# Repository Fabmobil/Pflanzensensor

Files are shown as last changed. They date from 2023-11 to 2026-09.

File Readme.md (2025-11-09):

# Fabmobil Logo Pflanzensensor

Dies ist das Repository mit dem Quellcode und allen Informationen zum Fabmobil Pflanzensensor. Weiterführende Erklärungen sind im [Wiki](https://github.com/Fabmobil/Pflanzensensor/wiki) zu finden.

Der Quellcode befindet sich im [Pflanzensensor](https://github.com/Fabmobil/Pflanzensensor/tree/main/Pflanzensensor)-Verzeichnis. Das [Dokumentation](https://github.com/Fabmobil/Pflanzensensor/tree/main/Dokumentation)-Verzeichnis enthält Datenblätter, Schaltpläne und Pinouts der verwendeten Bauteile sowie 3D Modelle für Zubehörteile, die gedruckt werden können. Im [Wiki](https://github.com/Fabmobil/Pflanzensensor/wiki) gibt es weiterführende Informationen und Anleitungen.

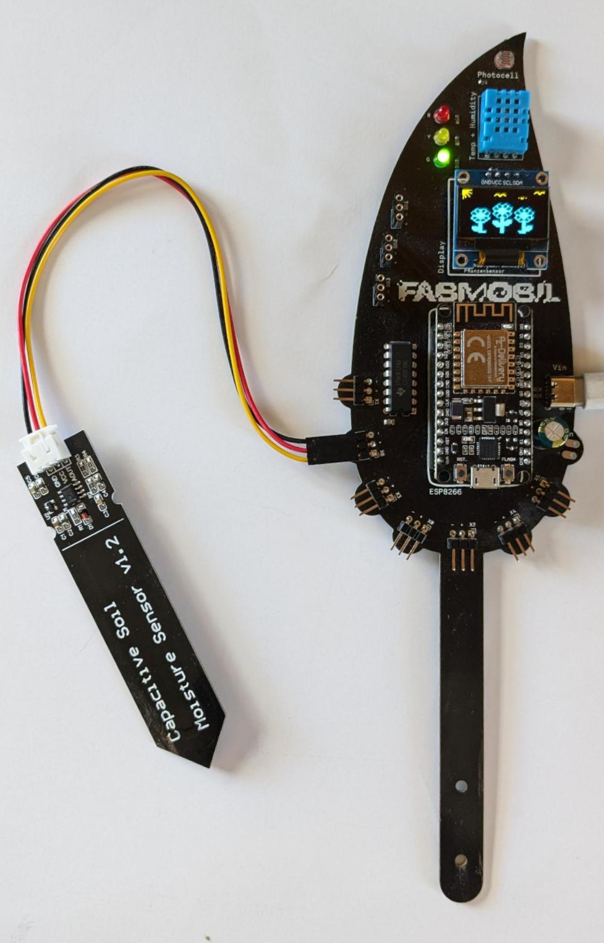
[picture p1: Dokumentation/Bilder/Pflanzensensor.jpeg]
Pflanzensensor

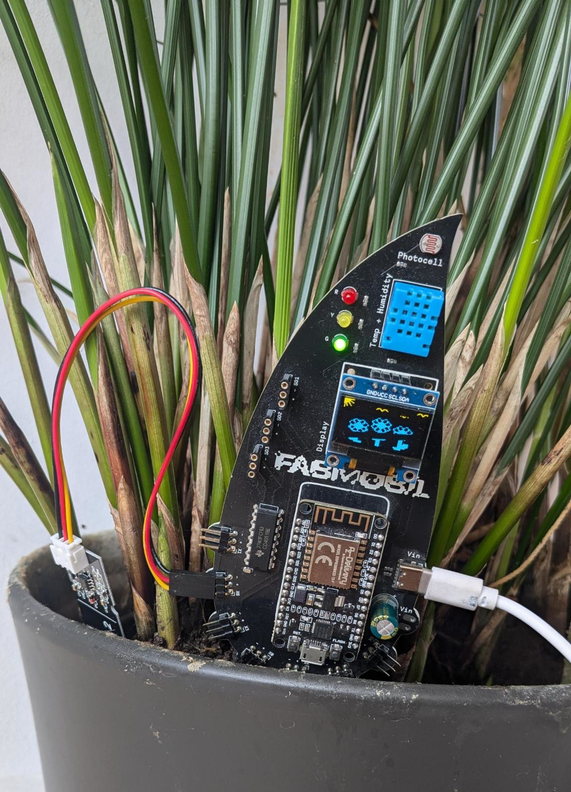
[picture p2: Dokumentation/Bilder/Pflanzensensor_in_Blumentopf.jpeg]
Pflanzensensor in Blumentopf

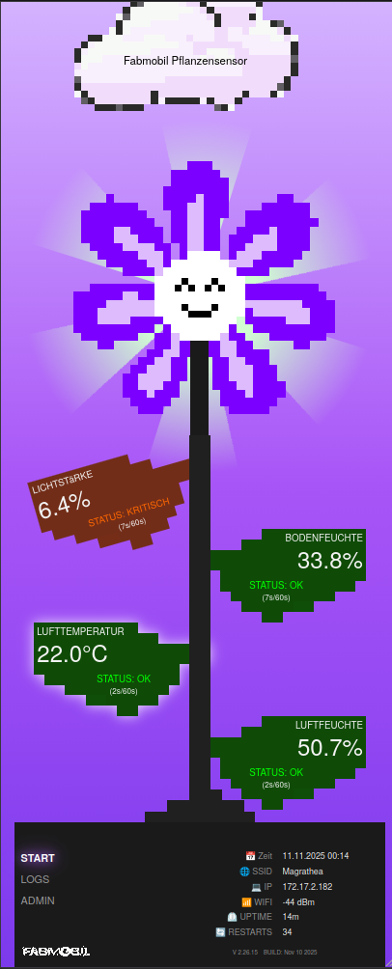
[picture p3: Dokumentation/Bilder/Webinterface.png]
Pflanzensensor Webinterface


[Bosch](https://www.fabmobil.org)

wird gefördert von:

[smk_logo](https://www.smk.sachsen.de/)

und unterstützt von:

[sisax](https://silicon-saxony.de) [Bosch](https://www.bosch.de/) [GlobalFoundries](https://gf.com/) [Bosch](https://www.infineon.com/) [Bosch](https://www.xfab.com/)

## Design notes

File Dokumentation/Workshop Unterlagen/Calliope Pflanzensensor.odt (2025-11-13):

Pflanzensensor Workshop

Willkommen beim Fabmobil Pflanzensensorworkshop! Dieses Dokument fasst die Inhalte und Aufgaben zusammen, die wir in den kommenden 3 Tagen gemeinsam bearbeiten werden und die du benötigst, damit du am Ende einen funktionierenden Pflanzensensor mit nach Hause nehmen kannst.

Achtung: Damit der Pflanzensensor am Ende bei dir zu Hause funktioniert musst du die WLAN Logindaten des WLANs eurer Wohnung eingeben. Du solltest also spätestens an Tag 3 den Namen und das Passwort des WLANs dabei haben, in dem du den Pflanzensensor betreiben willst bzw. vorher sicherstellen, dass du sie aus deinem Smartphone auslesen kannst (Family Link verhindert das z.B. manchmal). Sei achtsam beim Abschreiben: falls nur ein Zeichen falsch ist (Groß- und Kleinschreibung ist relevant!), wird es nicht funktionieren! Der eingesetzte Mikrocontroller kann nur 2,4GHz WLAN. Falls ihr zu Hause also 5 Ghz WLAN und 2,4 GHz WLAN habt benötigst du die Logindaten für letzteres.

# Ablauf

## Tag 1

- Anmeldung, Kennenlernen, Bustour
- Calliope Programmierung

## Tag 2

- Pflanzensensor mit Calliope bauen, kalibrieren, testen
- Arduino IDE kennenlernen

## Tag 3

- Einführung C-Programmierung in Arduino-IDE
- Pflanzensensor zusammenbauen
- Pflanzensensor konfigurieren und flashen
- Sensoren über Webinterface kalibrieren
- Testen
- Abschluss

# Aufgaben

## Kennenlernen

- macht euch ein Namensschild mit Kreppband: wenn ihr nicht fotografiert werden dürft nehmt ihr einen roten Stift, ansonsten nehmt ihr einen schwarzen Stift
- lasst euch den Bus zeigen und erklären
- meldet euch über das Anmeldeformular (https://fabmobil-survey.netlify.app/) an

## Calliope-Programmierung

### Einstieg

Eure WorkshopleiterInnen werden euch eine Einführung ins Thema geben. Wenn ihr die bekommen habt findet euch in Zweiergruppen zusammen. Pro Gruppe benötigt ihr:

- Einen Laptop inkl. Maus und Netzteil
- Einen Calliope inklusive MicroUSB-Kabel
- Ein Calliope Lernkartenbuch

Eure Aufgabe ist es, dass Calliope Lernkartenbuch durchzuarbeiten. Es erklärt euch alles, was ihr über den Calliope, dessen Programmierung und die dazugehörige Entwicklungsumgebung wissen müsst. Am Ende gibt es ein paar kleine Programmierherausforderungen. Wenn ihr die geschafft habt, seid ihr gut vorbereitet für die Programmierung des Pflanzensensors.

#### Bonus

Falls ihr früher als die anderen fertig seid, gibt es folgende Bonusaufgabe:

Sucht euch eine andere Gruppe die auch schon fertig ist. Ihr sollt ihr ein Schnick-Schnack-Schnuck Spiel programmieren, was mit zwei Calliopes gegeneinander gespielt werden kann. Hier ein paar Tipps:

- Zum Senden und Empfangen der Daten zwischen den Calliopes benötigt ihr das Funk-Modul. Ihr findet es hinter dem Button im Online-Editor
- als erstes wählt ihr auf eurem Calliope (z.B.: A = Schere, B = Stein, A + B = Papier) und speichert diese Wahl in einer Variable
- dann schickt diese Wahl an den anderen Calliope
- parallel empfangt ihr die Wahl des anderen Calliope und speichert sie in einer anderen Variable
- diese zwei Variablen müssen dann miteinander verglichen werden: Stein schlägt Schere, Schere schlägt Papier usw.
- danach müsst ihr nur noch das Ergebnis ausgeben: habt ihr gewonnen oder verloren?

### Calliope Pflanzensensor

Meldet euch dann bei euren WorkshopleiterInnen. Die geben euch einen Bodenfeuchtesensor und die notwendigen Kabel, um sie mit dem Calliope zu verbinden. Außerdem wird euch gezeigt, wie ein funktionierendes Pflanzensensorprogramm auf dem Calliope aussehen kann. Ihr sollt jetzt auch ein solches Programm entwerfen. Nutzt dafür das Wissen, was ihr durch die Lernkarten erworben habt. Wenn ihr nicht weiter kommt, fragt die WorkshopleiterInnen um Hilfe. Hier sind auch noch ein paar Tipps und Tricks:

- in der „Beim Start“-Funktion wollt ihr alle eure Variablen und deren Werte definieren. Ihr braucht insgesamt 7: Bodenfeuchte, BodenfeuchteMin, BodenfeuchteMax, TemperaturMin, TemperaturMax, LichtstärkeMin, LichtstärkeMax
- in der „Dauerhaft“-Schleife wollt ihr den Bodenfeuchtesensor an Analogpin P1 auslesen und in einer Variable speichern. Der Sensor arbeitet invertiert: ganz feucht entspricht dem Messwert 1023, ganz trocken dem Messwert 0. Unter den Mathematikblöcken gibt es einen Block der es euch ermöglicht, die Messwerte auf eine 0 – trocken bis 100 – nass Skala umzulegen:

Da diese Funktion eine Kommazahl ausgebt, könnt ihr noch die Runden-Funktion verweden um das Ergebnis auf eine ganze Zahl zu runden:

100

- Beim Drücken der Knöpfe A, B, A+B soll jeweils einer der Messwerte (Temperatur, Lichtstärke, Bodenfeuchte) angezeigt werden und die RGB-LED soll grün oder weiss sein, je nachdem ob der Messwert zwischen Minimum und Maximum liegt oder nicht. Für diesen Vergleich benötigt ihr folgende Blöcke aus dem Logik Bereich:

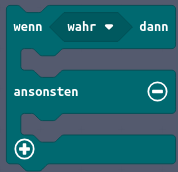
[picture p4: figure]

- Beim Drücken von P0 soll der Sensor alle Messwerte hintereinander anzeigen. Denkt euch jeweils ein schönes Symbol auf der LED-Matrix aus, damit klar ist, welcher Sensor gerade angezeigt wird

Wenn euer Calliope Pflanzensensor funktioniert, könnt ihr ihn mit feuchter und trockener Blumenerde kalibrieren und testen.

## Kennenlernen der Arduino-IDE

Nachdem ihr mit dem Calliope den Einstieg ins Programmieren gefunden habt, geht es mit der Arduino-IDE und der Programmiersprache C++ weiter.

Ihr arbeitet weiterhin in Zweiergruppen und benötigt für diesesen Teil:

- euren Laptop
- einen ESP8266-Microcontroller
- ein MicroUSB-Kabel um den Microcontroller mit eurem PC zu verbinden
- die Software „Arduino IDE“ (sie ist schon auf eurem Laptop installiert)
- den Bodenfeuchtesensor, den ihr schon mit eurem Calliope verwendet habt
- Den Spickzettel zur C-Programmierung (ein PDF im gleichen Verzeichnis wie diese Datei)

Als erstes kopiert ihr euch den Arduino-Ordner aus dem Workshopordner auf dem Netzlaufwerk in den Dokumente Ordner auf eurem Laptop. Dort sollte es schon einen Arduino Ordner geben, löscht ihn vorher damit ihr die aktuellen Versionen des Quellcodes habt:

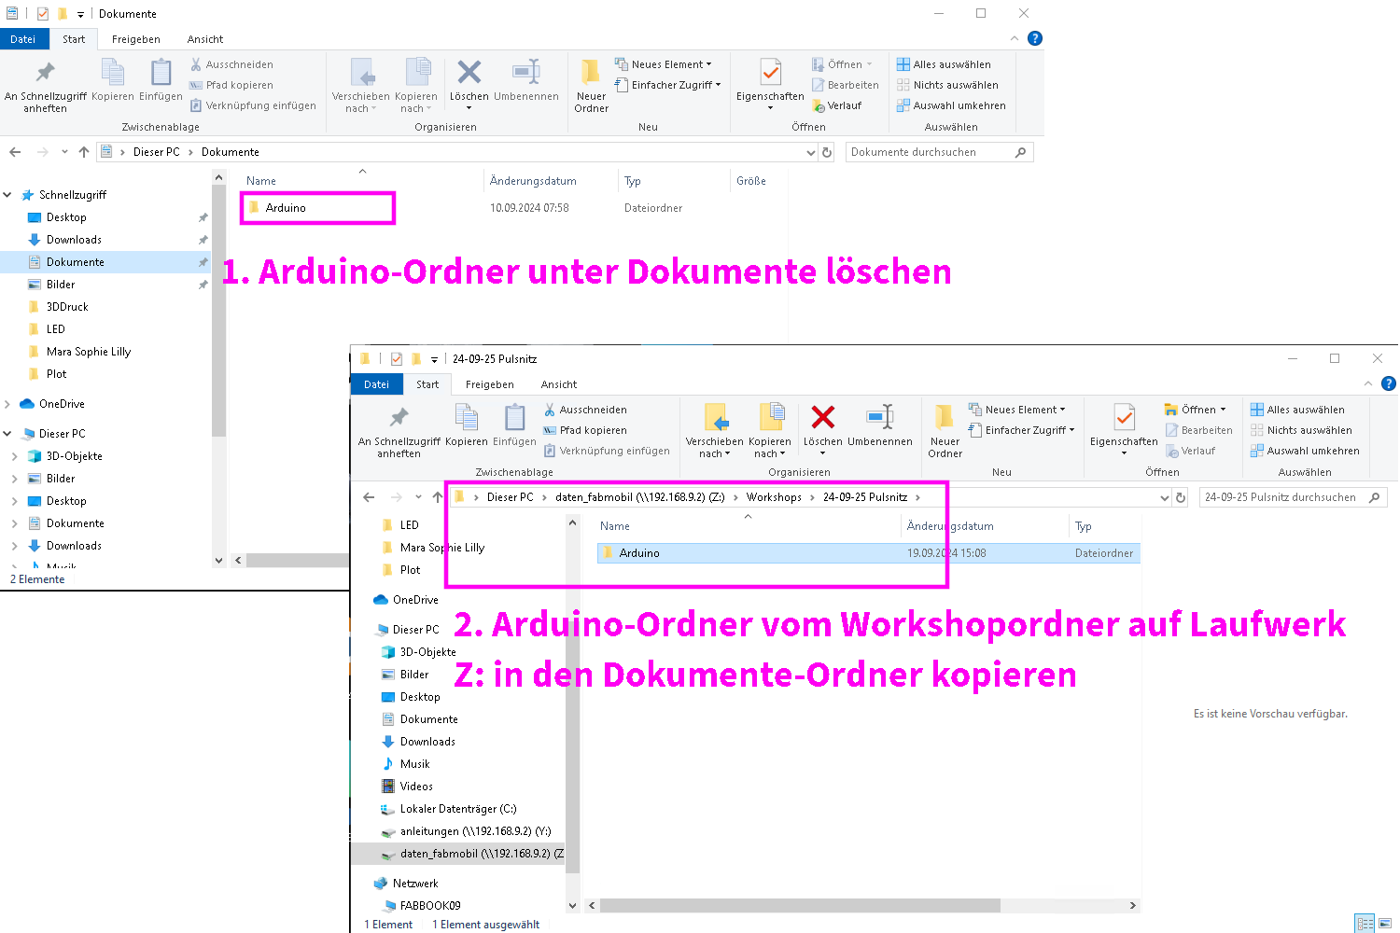
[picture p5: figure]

Dann öffnet ihr die Arduino IDE und schaut euch um. Hier ist ein Bild in dem die wichtigsten Bereiche markiert sind:

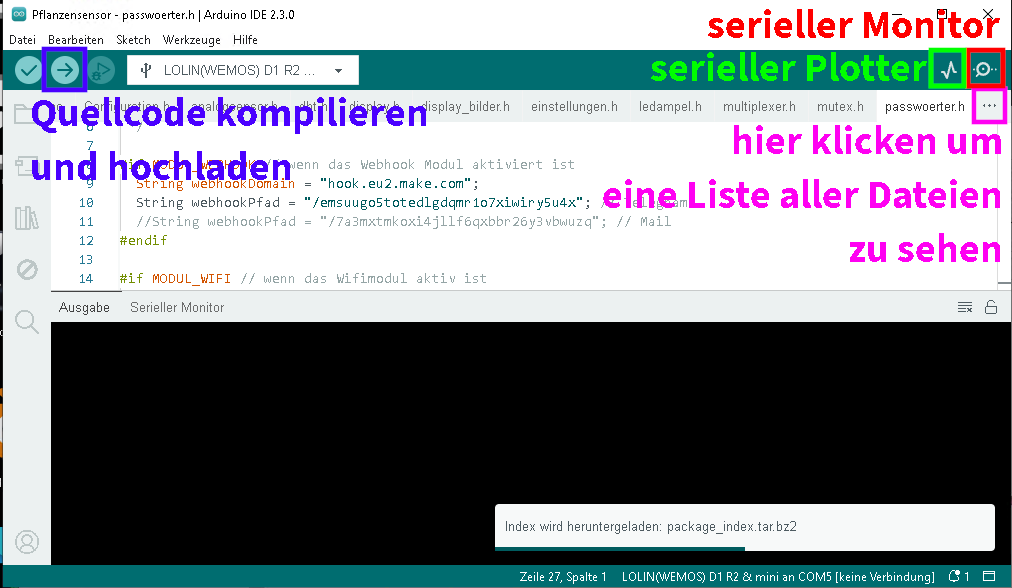
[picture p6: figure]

## Übungen zum Programmieren des ESP8266

Lest euch den Spickzettel durch. Auch wenn die dahinter liegenden Konzepte die Gleichen sind, ist das Programmieren in C ganz anders als die grafische Programmierung des Calliopes. Lasst euch nicht abschrecken: es ist noch kein*e Programmierer*In vom Himmel gefallen. Versucht euch durchzuhangeln und helft euch gegenseitig bzw. fragt die Workshopleiter*Innen wenn ihr nicht weiter kommt!

### Aufgabe 1: LED blinken lassen

- öffne LED.ino im LED Verzeichnis in der Arduino IDE
- verbinde den ESP8266 per USB Kabel mit deinem Laptop
- überspiele das Programm auf deinen ESP8266:
  - klicke unter Werkzeuge auf Board, wähle dann ESP8266 Boards und danach LOLIN(WEMOS) D1 R2 & mini
  - klicke unter Werkzeuge auf Port und wähle den COM-Port mit der höheren Nummer aus. (Falls mit diesem das Überspielen nicht funktioniert, kann es auch sein, dass es der andere Port der Richtige ist)
- überprüfe, ob die interne LED an ist
- erweitere das Programm so, dass die LED immer abwechselnd 1 Sekunde an und 2 Sekunden aus ist. Dazu benötigst du die folgenden zwei zusätzlichen Befehle:
  - digitalWrite(LED, HIGH); schaltet die LED aus
  - delay(3000); pausiert das Programm für 3000ms, also 3 Sekunden

### Aufgabe 2: Feuchtesensor auslesen

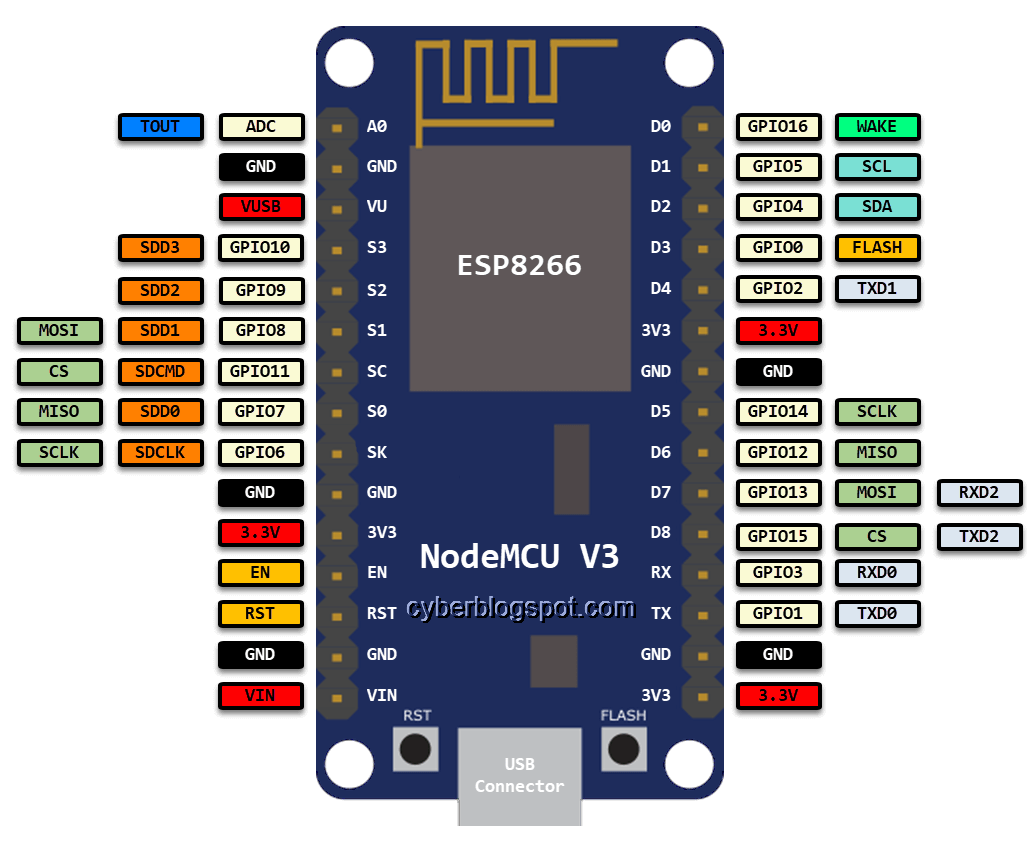
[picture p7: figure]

- Schließe den Bodenfeuchtesensor mit Hilfe von Jumperkabeln an deinen ESP8266 an: rot kommt an 3V3 (Versorgungsspannung), schwarz an GND (Masse) und Gelb an A0 (Sensorwert). Die Pins sind beschriftet bzw. kannst du sie rechts ablesen.
- öffne feuchtesensor.ino in der Arduino IDE
- überspiele das Programm auf deinen ESP8266
- schau dir die Messwerte im seriellen Monitor und im seriellen Plotter an.
- Nimm den Sensor in die Hand und beobachte, wie sich der Wert verändert
- Der Wert liegt immer zwischen 0 und 1024
- deine Aufgabe ist es nun, die interne LED entsprechend dem Wert des Analogsensors blinken zu lassen: bei einem Sensorwert von 100 soll die LED für 100ms an und dann für 100ms aus sein. Bei einem Sensorwert von 1000 soll die LED für 1000ms an und dann für 1000ms aus sein.

### Aufgabe 3: Schwellwertvergleich

- öffne schwellwert.ino in der Arduino IDE
- Vergleiche die Variable schwellwert mit der Variable sensorwert: wenn der sensorwert größer als der schwellwert ist, soll die LED an sein. Wenn der sensorwert kleiner oder gleich dem schwellwert ist, soll die LED aus sein
- wie du einen solchen Vergleich progammierst kannst du hier nachlesen: https://docs.arduino.cc/language-reference/de/struktur/control-structure/else/

### Bonus

Wenn du früher als alle anderen fertig bist, kannst du dir ein Arduinobuch aus der Fabmobil Bibliothek nehmen und dir dort ein kleines Arduino-Programmierprojekt heraussuchen. Sprich mit deinen WorkshopleiterInnen: fast alle der in den Büchern verwendeten Sensoren haben wir auch im Fabmobil und du kannst sie gern ausprobieren.

Die Arduino IDE hat auch viele Beispielprogramme die ausprobiert und verstanden werden wollen. Klick doch mal auf Datei und dann auf Beispiele und schau, was du da so findest!

## Pflanzensensor

Endlich ist es so weit und wir kümmern uns um euren ganz persönlichen Pflanzensensor! Du benötigst:

- einen ESP8266 Mikrocontroller
- einen Bodenfeuchtesensor
- ein Display
- ein Pflanzensensor PCB
- einen Laptop
- ein MicroUSB-Kabel
- Abstandshalter und Schrauben aus Plastik
- 3D-gedruckte Hülle für den Bodenfeuchtsensor

### Zusammenbau

Baue als erstes deinen Pflanzensensor zusammen:

- der ESP8266 kommt in die Fassung auf dem PCB. Achtung: der USB-Port muss nach unten zeigen!
- Das Display kommt in die Fassung über dem ESP8266. Fixiert es mit Plastikabstandshaltern und Schrauben: es gibt entsprechende Löcher auf dem PCB und im Display
- steckt den Bodenfeuchtesensor an: er kommt an den Port der mit X6 gelabelt ist. Passt auf die Orientierung des Kabels auf: - am PCB muss an GND am Sensor
- Setzt das Gehäuse um den oberen Teil des Bodenfeuchtesensors. Es schützt die elektronischen Bauteile davor, dass sie beim Blumengießen Spritzwasser abbekommen und dadurch eventuell kaputt gehen.
  - Falls das Gehäuse nicht hält könnt ihr es mit Klebeband oder Sekundenkleber zusammenkleben.

### Bespielen des ESP8266 mit dem Pflanzensensorprogramm

Folgende Schritte sind zu tun:

- öffnet die Pflanzensensor.ino – Datei in eurer Arduino IDE. Sie liegt im Dokumente/Arduino/Pflanzensensor-Ordner
- der Quellcode des Pflanzensensorprogramms besteht aus vielen Dateien. Sie werden alle automatisch geöffnet und ihr seht sie in der Leiste über dem Editor in der Arduino IDE. Schaut euch ruhig um und in die Dateien rein, falls es euch interessiert. Es ist allerdings wichtig, dass ihr nichts verändert, denn dann ist die Chance groß, dass ihr Fehler einbaut und das Programm sich später nicht mehr überspielen lässt
- Verändern müsst ihr nur die passwoerter.h- Datei. Falls ihr diese in der Leiste mit den Dateinamen nicht findet könnt ihr rechts auf die drei … klicken, dann bekommt ihr eine Liste mit allen geöffneten Dateien angezeigt und könnt sie dort auswählen
- Öffnet die passwoerter.h-Datei und tragt dort die Daten des WLANs ein, in dem ihr den Pflanzensensor betreiben wollt:
  - Ihr könnt bis zu drei verschiedene WLANs konfigurieren. Die Variablen wifiSsid1, wifiSsid2 und wifiSsid3 speichern den Namen des WLANs und die Variablen wifiPassword1, wifiPassword2 und wifiPassword3 speichern das Passwort der WLANs. Der eigentliche Name des WLANs bzw. das Passwort kommt zwischen die Anführungszeichen.
  - Passt auf, dass ihr die schon ausgefüllten Fabmobil WLAN Daten nicht löscht oder verändert, sonst kann sich euer Sensor nicht mit dem WLAN im Fabmobil verbinden und ihr könnt euch nicht mit eurem Laptop zum Webinterface verbinden
  - Falls ihr plant, den Sensor mobil zu benutzen, ist es eventuell sinnvoll, auch die Daten eures Handy WLAN Hotspots einzutragen
- Danach könnt ihr den Quellcode kompilieren und überspielen so wie ihr das bei den Programmierübungen auch schon gemacht habt.
- Abschließend müsst ihr noch ein paar Extradateien überspielen. Das funktioniert, in dem ihr [Strg] + [Shift] + [P] gleichzeitig drückt, upload eingebt und Upload LittleFS to Pico/ESP8266/ESP32 auswählt.
- Öffnet jetzt den seriellen Monitor und startet den ESP neu. Achtet auf die Zeile Start von Wifi-Modul…: jetzt versucht sich euer Pflanzensensor mit dem WLAN zu verbinden. Wenn das geklappt hat wird euch auf dem Display und auch im seriellen Monitor die IP Adresse angezeigt, die der Pflanzensensor bekommen hat. IP Adressen bestehen aus vier Zahlen getrennt durch einen Punkt und sehen z.B. so aus: 192.168.9.199. Merkt oder kopiert sie euch.

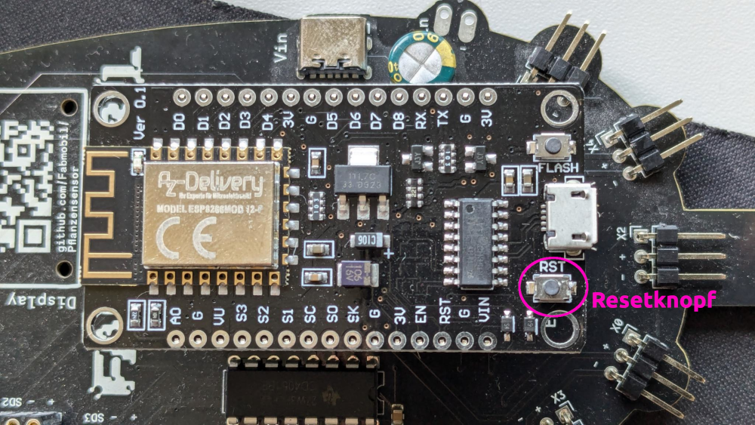
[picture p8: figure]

- Gebt diese IP-Adresse jetzt im Browser eures Laptops als Adresse ein. Ihr solltet jetzt auf dem Webinterface eures Pflanzensensors landen.

### Kennenlernen des Webinterfaces

- Schaut euch das Webinterface eures Pflanzensensors im Browser an, versteht was es darstellt, findet die Adminseite und lest hier (https://github.com/Fabmobil/Pflanzensensor/wiki/Webinterface) nach, was da alles eingestellt werden kann.

### Kalibrieren der Sensoren

Damit euer Bodenfeuchtesensor richtig funktioniert, müsst ihr ihn jetzt kalibrieren:

- Stecke den Bodenfeuchtesensor in sehr feuchte Erde. Achtung: Du solltest den Sensor immer gleich tief in die Erde stecken damit die Messung einigermaßen genau ist. Ein Sensor, der nur halb in der Erde steckt, wird dir andere Messwerte anzeigen als einer, der ganz in der Erde steckt. Ein weißer Strich auf dem Sensor kurz unterhalb des Gehäuses markiert die Stelle, bis zu der ihr den Sensor in die Erde stecken solltet.
- Geh auf die Adminseite deines Pflanzensensors, finde dort den Bodenfeuchte-Bereich und lese den aktueller absoluter Messwert ab. Dieser muss nun darunter bei Maximalwert eingetragen werden.
- Stecke den Bodenfeuchtesensor in sehr trockene Erde.
- Lies wieder den aktuellen absoluten Messwert ab und trage ihn diesmal bei Minimalwert ein.
- Speichere deine Änderungen.
- Jetzt ist dein Bodenfeuchtesensor kalibriert. Falls du allerdings später zu Hause andere Erde hast kann es sein, dass du die Kalibrierung dort noch einmal wiederholen musst.
- Wenn du willst, kannst du auch deinen Helligkeitssensor kalibrieren: bedecke ihn damit es ganz dunkel ist und halte ihn in die Mittagssonne. Die voreingestellten Werte passen aber ganz gut, so dass du das nicht zwingend machen musst.

### Einstellen der Grenzen für die LED Ampel

Die Grenzwerte der LED Ampel für die unterschiedlichen Sensoren können auf der Adminseite deines Pflanzensensors eingestellt werden:

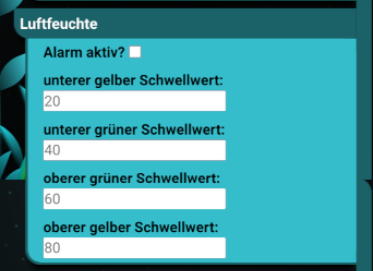
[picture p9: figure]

Diese Schwellwerte sind folgendermaßen definiert:

Abhängig davon, was die Pflanze die du mit dem Sensor überwachen willst für Bedürftnisse hat, stellst du jetzt die Skale für die unterschiedlichen Sensoren ein.

### Bonus

Wenn ihr noch genügend Zeit und Motivation habt könnt ihr eurem Pflanzensensor noch beibringen, euch per Telegram oder Email zu benachrichtigen, falls eure Pflanze eure Aufmerksamkeit benötigt. Dazu müsst ihr:

- in der Arduino IDE die Datei einstellungen.h öffnen und in der Zeile #define MODUL_WEBHOOK false das false zu einem true ändern. Das aktiviert das Webhook-Modul, welches für die Benachrichtigung notwendig ist.
- Öffnet dann diese Anleitungsseite (https://github.com/Fabmobil/Pflanzensensor/wiki/Webhook) in eurem Browser und arbeitet sie durch.

## Wie weiter?

Ihr bekommt ja jede*r einen Pflanzensensor mit nach Hause. Im besten Fall wisst ihr nun, wie ihr ihn konfigurieren und einsetzen könnt.
Unter https://www.github.com/fabmobil/pflanzensensor findet ihr die Dokumentation und den Quellcode zu eurem Sensor. Dort werden auch Aktualisierungen des Pflanzensensor-Programms veröffentlicht. Falls ihr in ein paar Wochen vergessen habt, wir ihr das Pflanzensensor Programm flashen könnt, steht das dort auch geschrieben. Wusstet ihr, dass ihr noch mehr Bodenfeuchtesensoren anschließen könnt um mehrere Pflanzen gleichzeitig zu überwachen? Oder das euer Pflanzensensor euch per Mail oder Telegram Bescheid sagen kann, wenn eure Pflanze euch braucht (https://github.com/Fabmobil/Pflanzensensor/wiki/Webhook)?
Falls ihr Fragen oder Anregungen habt könnt ihr uns auch gern per Email kontaktieren: pflanzensensor@fabmobil.org

Vielleicht findet ihr den Pflanzensensor ja aber auch doof und wollt lieber ganz andere Sachen mit eurem WLAN-fähigen Mikroprozessor machen? Kein Problem: zieht ihn einfach aus dem PCB raus und widmet ihn um. Das Internet ist voll mit Tutorials und Anleitungen, wenn ihr Inspiration braucht könnt ihr zum Beispiel hier mal schmökern: https://polluxlabs.net/esp8266-projekte/

Viel Spaß❣️

# Verwendete Programme und Links

## Calliope

- Calliope Lernkarten aus dem Fabmobil
- Calliope Online Editor (https://makecode.calliope.cc/)
- Einfühungs Tutorial auf Youtube (https://www.youtube.com/watch?v=76ryLoWfYhs)

## Pflanzensensor

- Arduino IDE (https://www.arduino.cc/en/software)
- Pflanzensensor Quellcode und Erklärungen (https://github.com/Fabmobil/Pflanzensensor)
- Anleitungen im Pflanzensensor Wiki:
  - Pflanzensensor konfigurieren und bespielen (https://github.com/Fabmobil/Pflanzensensor/wiki/Update)
  - Erklärungen zum Webinterface (https://github.com/Fabmobil/Pflanzensensor/wiki/Webinterface)
  - Webhook für Telegram- oder Mailbenachrichtigungen einrichten (https://github.com/Fabmobil/Pflanzensensor/wiki/Webhook)
  - make.com Website für Mail- oder Telegrambenachrichtgungen (https://www.make.com/en)

## Fabmobil und Silicon Saxony

- 💜 Fabmobil Homepage (https://fabmobil.org/) 💜
- 🩵 Silicon Saxony (https://silicon-saxony.de/) 🩵
- 🧡 Bosch (https://www.bosch.de/) 🧡
- 💚 Global Foundries (https://gf.com/) 💚
- 🩷 Infineon (https://www.infineon.com/) 🩷
- 🩶 Xfab (https://www.xfab.com/) 🩶

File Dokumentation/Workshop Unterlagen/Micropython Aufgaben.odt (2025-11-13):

# Aufgaben

## Den ESP8266 einrichten

Öffne das Programm, schließe deinen ESP8266 über USB an und gehe direkt auf den Punkt Werkzeuge → Optionen:

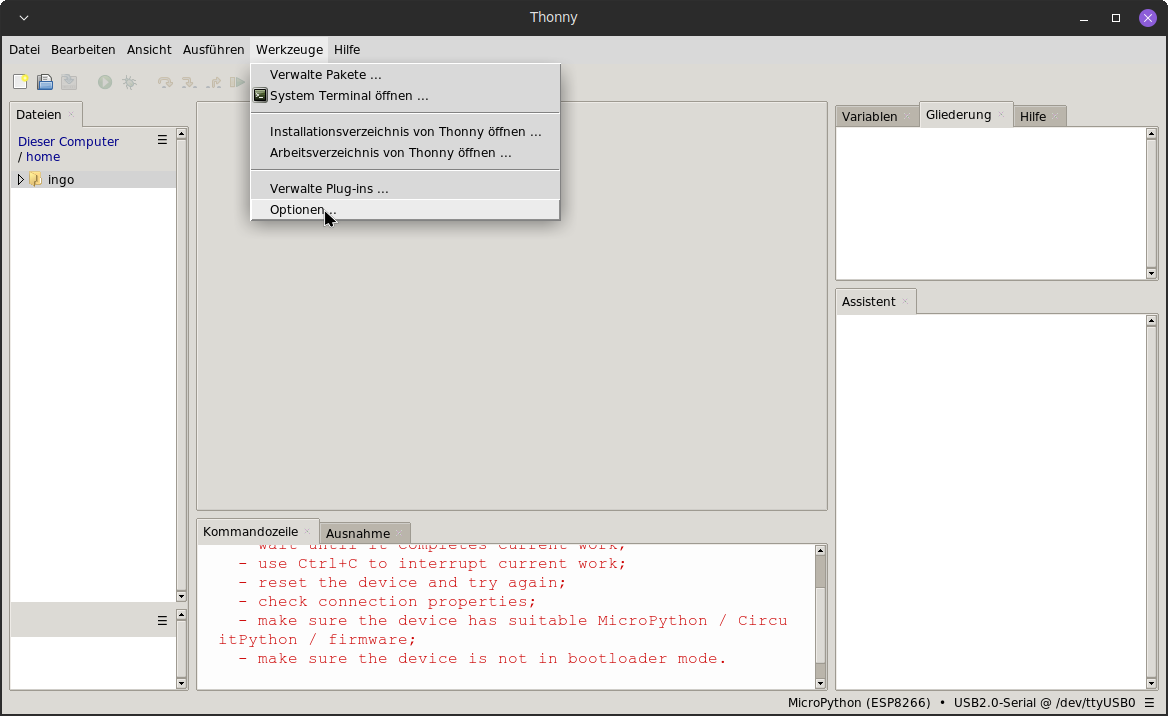
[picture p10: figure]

Dort sollte unter dem Reiter „Interpreter“ euer ESP8266 automatisch erkannt werden. Falls ihr ihn nicht finden könnt, meldet ihr euch bei uns.

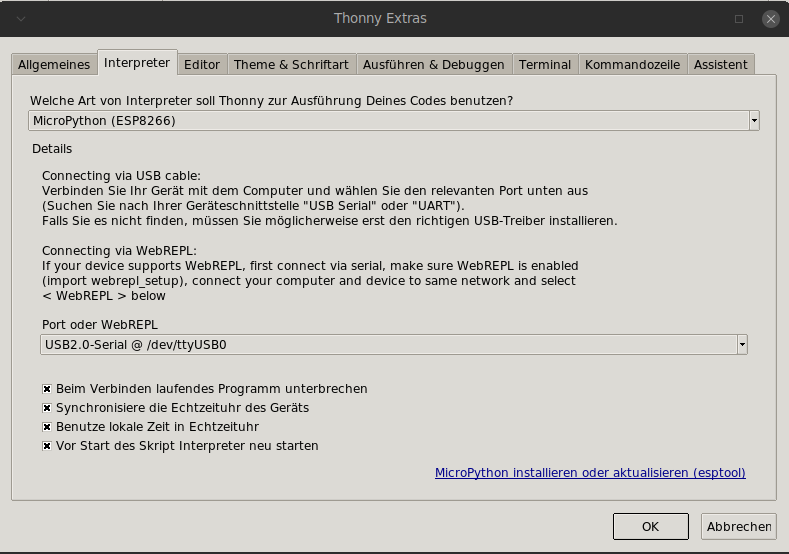
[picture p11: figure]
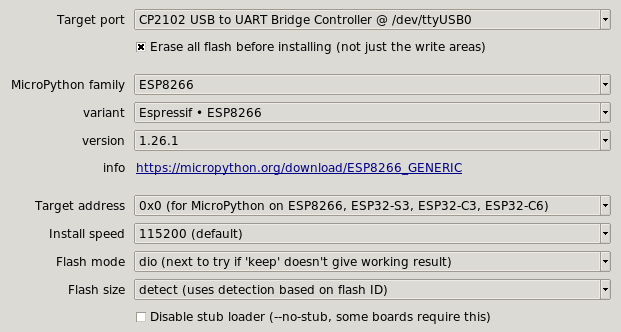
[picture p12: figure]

## Hello World

Schreibe den Befehl

print(„Hallöchen“)

in die Kommandozeile unten in Thonny hinein und drücke Enter. Erscheint dein Text in der nächsten Zeile?

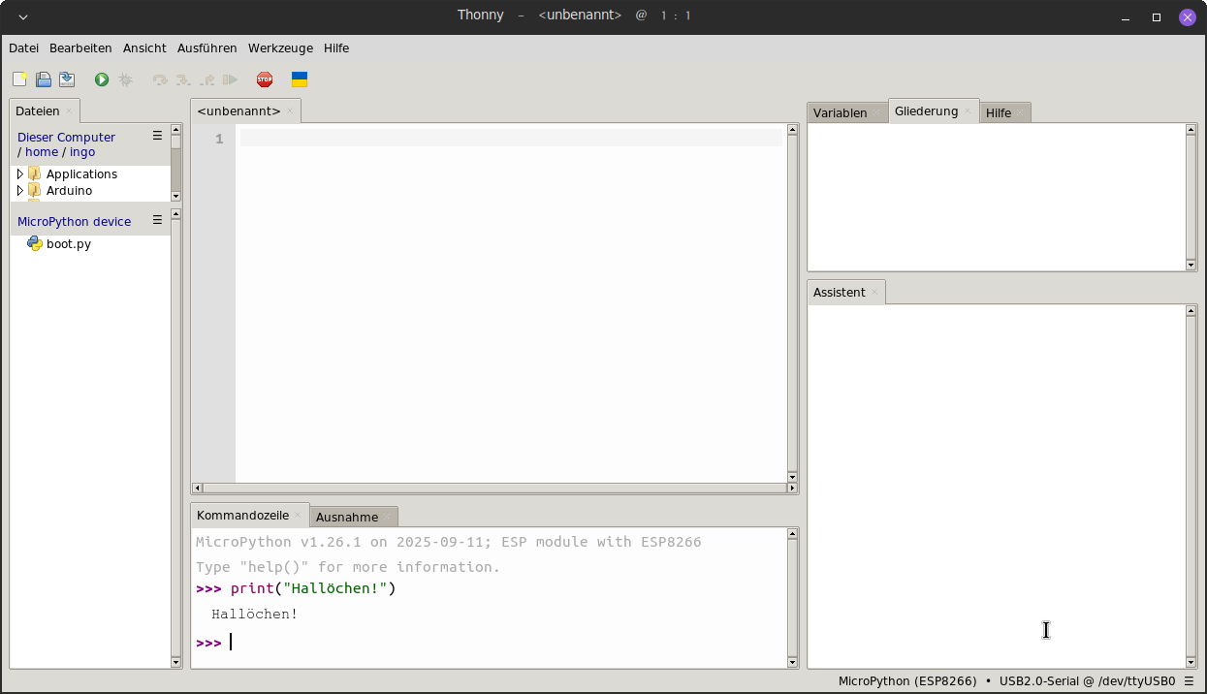
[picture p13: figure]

Der Befehl print() ist mit dem „Zeige Text“-Block von Makecode vergleichbar, den wir vorher auch schon genutzt haben, um uns die Sensorwerte anzeigen zu lassen.

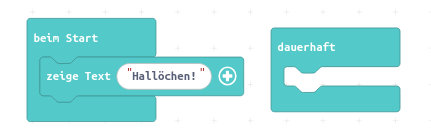
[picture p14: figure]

Aufgabe: Lege eine Variable text mit dem Inhalt „Hallöchen“ an:

text = „Hallöchen“

Gebe mit print() die Variable ausgeben und überprüfe den Inhalt.

Aufgabe: Lege die Variable zahl mit dem Inhalt 3 an:

zahl = 3

Erhöhe die Variable um 4 und gebe den neuen Wert mit print() aus.

## Blinky LED

Füge die externe Bibliothek Pin mit der folgenden Zeile hinzu:

from machine import Pin

Bibliotheken sind so etwas wie Plugins. Ab jetzt kannst du den Befehl Pin() verwenden.

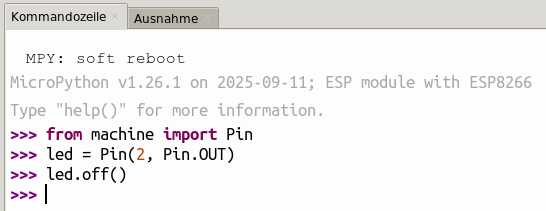
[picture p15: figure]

Achtung! Die LED auf dem ESP geht mit led.off() an und mit led.on() wieder aus – es ist genau umgedreht.

Aufgabe: Probiere die anderen LEDs auf dem Pflanzensensor aus. Sie sind an die folgenden Pins angeschlossen:
grün – Pin 14
gelb – Pin 12
rot – Pin 13

Aufgabe: Was ist led genau? Tipp: Die Struktur mit dem = Zeichen haben wir in der letzten Aufgabe schon benutzt.

## Poesie

In dem Programmtext-Fenster kannst du mehrere Befehle jeweils in eine Zeile untereinander schreiben. Diese werden der Reihe nach ausgeführt, wenn du auf den grünen Pfeil klickst.

Programmtext-Fenster

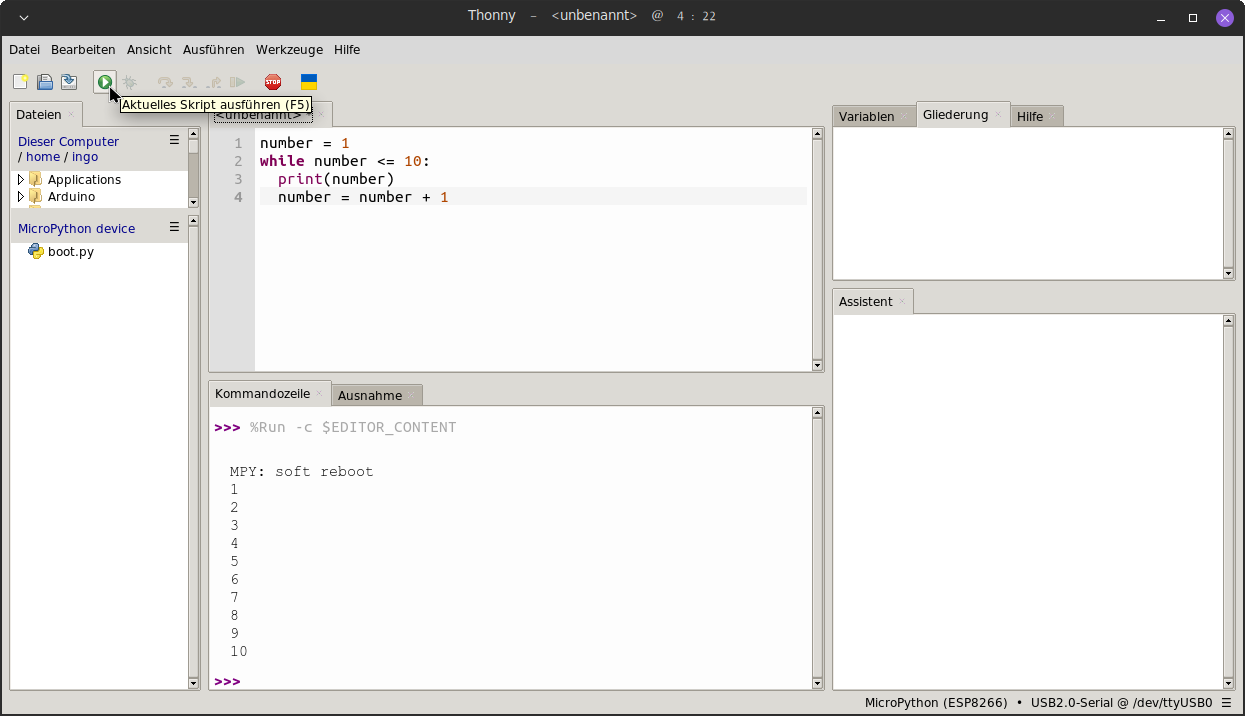
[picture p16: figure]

Aufgabe: Lasse dir ein selber ausgedachtes Gedicht mit 4-5 Zeilen untereinander ausgeben.

Aufgabe: Lasse nach jeder Zeile des Gedichts eine beliebige LED für jeweils eine Sekunde aufleuchten und anschließend wieder ausgehen. Dafür benötigst du den Befehl sleep(sekunden) , damit wartet dein ESP einfach für die in sekunden eingetragene Zeit, z.B. sleep(3) für 3s. Den Befehl sleep() kannst du erst benutzen, nachdem du ihn mit from time import sleep eingebunden hast.

### Schleifen

Eine Schleife wiederholt einen Block des Quellcodes. In Makecode habt ihr das z.B. für die Lärmampel benutzt:

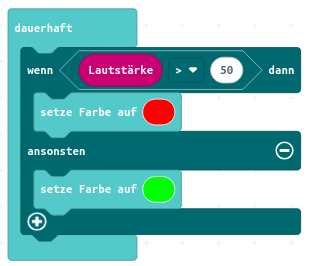
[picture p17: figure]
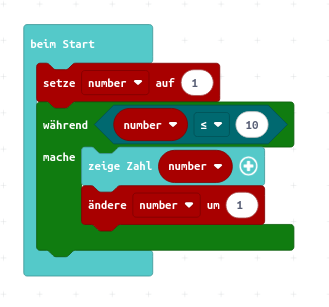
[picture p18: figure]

In Python gibt es stattdessen die while-Schleife (englisch für „während“):

Aufgabe: Schreibe ein Programm, das Zahlen von 1 bis 10 ausgibt (so wie rechts). Achte in Python auf die gleichen Einrückungen für den Block!

Aufgabe: Wenn dir jetzt noch nicht klar ist, wie while funktioniert, Google nach weiteren Informationen oder lasse es dir von einem Chatbot erklären.

Aufgabe: Lasse jetzt die Zahlen endlos nach oben zählen, solange der ESP Strom hat (vergleichbar mit der Dauerhaft-Schleife von Makecode).

Bonus: Lasse jetzt noch bei jeder Zahl eine LED kurz aufblinken.

## Den Sensor auslesen

Um den Sensor auszulesen benötigen wir die Bibliothek

from machine import ADC

Lege eine Variable bodenfeuchte_sensor mit dem Inhalt ADC(0) an.

Lese den aktuellen Messwert ein mit: bodenfeuchte_sensor.read()

Aufgabe: Gebe den aktuellen Messwert dauerhaft aus, solange der ESP Strom hat. Füge zwischen zwei Messungen eine kleine Pause ein, damit die Zahlen nicht zu schnell kommen.

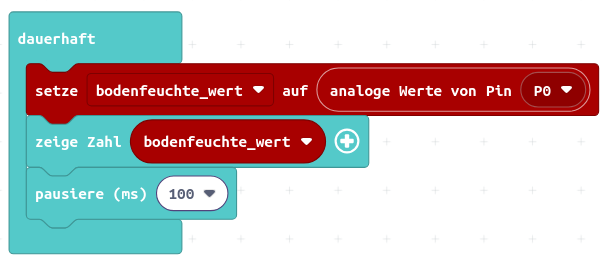
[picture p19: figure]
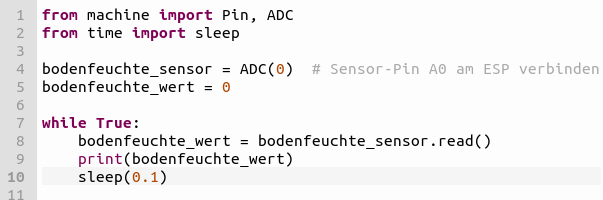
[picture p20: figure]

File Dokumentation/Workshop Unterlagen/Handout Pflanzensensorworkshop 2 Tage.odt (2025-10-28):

Pflanzensensor Workshop

Willkommen beim Fabmobil Pflanzensensorworkshop! Dieses Dokument fasst die Inhalte und Aufgaben zusammen, die wir in den kommenden 2 Tagen gemeinsam bearbeiten werden und die du benötigst, damit du am Ende einen funktionierenden Pflanzensensor mit nach Hause nehmen kannst.

# Ablauf

## Tag 1

- Anmeldung, Kennenlernen, Bustour
- Calliope Programmierung:
  - Kennenlernen und Programmierchallenges
  - Pflanzensensor bauen, programmieren, kalibrieren, testen

## Tag 2

- Fertigstellen Calliope Pflanzensensor
- Programmierübungen mit Micropython auf dem ESP8266
- Pflanzensensor zusammenbauen
- Pflanzensensor flashen
- Pflanzensensor kennenlernen und über Webinterface einstellen
- Testen
- Abschluss

# Aufgaben

## Kennenlernen

- macht euch ein Namensschild mit Kreppband: wenn ihr nicht fotografiert werden dürft nehmt ihr einen roten Stift, ansonsten nehmt ihr einen schwarzen Stift
- lasst euch den Bus zeigen und erklären
- meldet euch über das Anmeldeformular (https://fabmobil-survey.netlify.app/) an

## Calliope-Programmierung

### Einstieg

Eure WorkshopleiterInnen werden euch eine Einführung ins Thema geben. Wenn ihr die bekommen habt findet euch in Zweiergruppen zusammen. Pro Gruppe benötigt ihr:

- Einen Laptop inkl. Maus und Netzteil
- Einen Calliope inklusive MicroUSB-Kabel
- Ein Calliope Lernkartenbuch

Eure Aufgabe ist es, dass Calliope Lernkartenbuch durchzuarbeiten. Es erklärt euch alles, was ihr über den Calliope, dessen Programmierung und die dazugehörige Entwicklungsumgebung wissen müsst. Am Ende gibt es ein paar kleine Programmierherausforderungen. Wenn ihr die geschafft habt, seid ihr gut vorbereitet für die Programmierung des Pflanzensensors.

#### Bonus 1

Versucht auch mal in makecode.calliope.cc von der „Blöcke“-Ansicht auf die „Python“-Ansicht umzuschalten. Python ist eine sehr anfängerfreundliche Programmiersprache und alles, was ihr bisher in Blöcken programmiert habt, kann auch in Python programmiert werden. Schaut euch eine der Programmierchallenges als Pythoncode an. Versteht ihr, was ihr seht? Gelingt es euch, eine andere Programmierchallenge in Python zu schreiben anstatt sie mit Blöcken zu programmieren?

#### Bonus 2

Sucht euch eine andere Gruppe die auch schon fertig ist. Ihr sollt ihr ein Schnick-Schnack-Schnuck Spiel programmieren, was mit zwei Calliopes gegeneinander gespielt werden kann. Hier ein paar Tipps:

- Zum Senden und Empfangen der Daten zwischen den Calliopes benötigt ihr das Funk-Modul. Ihr findet es hinter dem Button im Online-Editor
- als erstes wählt ihr auf eurem Calliope (z.B.: A = Schere, B = Stein, A + B = Papier) und speichert diese Wahl in einer Variable
- dann schickt diese Wahl an den anderen Calliope
- parallel empfangt ihr die Wahl des anderen Calliope und speichert sie in einer anderen Variable
- diese zwei Variablen müssen dann miteinander verglichen werden: Stein schlägt Schere, Schere schlägt Papier usw.
- danach müsst ihr nur noch das Ergebnis ausgeben: habt ihr gewonnen oder verloren?

### Calliope Pflanzensensor

Meldet euch dann bei euren WorkshopleiterInnen. Die geben euch einen Bodenfeuchtesensor und die notwendigen Kabel, um sie mit dem Calliope zu verbinden. Außerdem wird euch gezeigt, wie ein funktionierendes Pflanzensensorprogramm auf dem Calliope aussehen kann. Ihr sollt jetzt auch ein solches Programm entwerfen. Nutzt dafür das Wissen, was ihr durch die Lernkarten erworben habt. Wenn ihr nicht weiter kommt, fragt die WorkshopleiterInnen um Hilfe. Hier sind auch noch ein paar Tipps und Tricks:

- in der „Beim Start“-Funktion wollt ihr alle eure Variablen und deren Werte definieren. Ihr braucht insgesamt 7: Bodenfeuchte, BodenfeuchteMin, BodenfeuchteMax, TemperaturMin, TemperaturMax, LichtstärkeMin, LichtstärkeMax
- in der „Dauerhaft“-Schleife wollt ihr den Bodenfeuchtesensor an Analogpin P1 auslesen und in einer Variable speichern. Der Sensor arbeitet invertiert: ganz feucht entspricht dem Messwert 1023, ganz trocken dem Messwert 0. Unter den Mathematikblöcken gibt es einen Block der es euch ermöglicht, die Messwerte auf eine 0 – trocken bis 100 – nass Skala umzulegen:

Da diese Funktion eine Kommazahl ausgebt, könnt ihr noch die Runden-Funktion verweden um das Ergebnis auf eine ganze Zahl zu runden:

100

- Beim Drücken der Knöpfe A, B, A+B soll jeweils einer der Messwerte (Temperatur, Lichtstärke, Bodenfeuchte) angezeigt werden und die RGB-LED soll grün oder weiss sein, je nachdem ob der Messwert zwischen Minimum und Maximum liegt oder nicht. Für diesen Vergleich benötigt ihr folgende Blöcke aus dem Logik Bereich:


- Beim Drücken von P0 soll der Sensor alle Messwerte hintereinander anzeigen. Denkt euch jeweils ein schönes Symbol auf der LED-Matrix aus, damit klar ist, welcher Sensor gerade angezeigt wird

Wenn euer Calliope Pflanzensensor funktioniert, könnt ihr ihn mit feuchter und trockener Blumenerde kalibrieren und testen.

## Programmierübungen mit Micropython auf dem ESP8266

Nachdem ihr mit dem Calliope den Einstieg ins Programmieren gefunden habt, geht es mit der Entwicklungsumgebung Thonny und der Programmiersprache Python weiter.

Ihr arbeitet weiterhin in Zweiergruppen und benötigt für diesesen Teil:

- euren Laptop
- einen ESP8266-Microcontroller
- ein MicroUSB-Kabel um den Microcontroller mit eurem PC zu verbinden
- die Software „Thonny“ (sie ist schon auf eurem Laptop installiert)
- den Bodenfeuchtesensor, den ihr schon mit eurem Calliope verwendet habt

TBC

## Pflanzensensor

Endlich ist es so weit und wir kümmern uns um euren ganz persönlichen Pflanzensensor! Du benötigst:

- einen ESP8266 Mikrocontroller
- einen Bodenfeuchtesensor
- ein Display
- ein Pflanzensensor PCB
- einen Laptop
- ein MicroUSB-Kabel
- Abstandshalter und Schrauben aus Plastik
- 3D-gedruckte Hülle für den Bodenfeuchtsensor

### Zusammenbau

Baue als erstes deinen Pflanzensensor zusammen:

- der ESP8266 kommt in die Fassung auf dem PCB. Achtung: der USB-Port muss nach unten zeigen!
- Das Display kommt in die Fassung über dem ESP8266. Fixiert es mit Plastikabstandshaltern und Schrauben: es gibt entsprechende Löcher auf dem PCB und im Display
- steckt den Bodenfeuchtesensor an: er kommt an den Port der mit X6 gelabelt ist. Passt auf die Orientierung des Kabels auf: - am PCB muss an GND am Sensor
- Setzt das Gehäuse um den oberen Teil des Bodenfeuchtesensors. Es schützt die elektronischen Bauteile davor, dass sie beim Blumengießen Spritzwasser abbekommen und dadurch eventuell kaputt gehen.
  - Falls das Gehäuse nicht hält könnt ihr es mit Klebeband oder Sekundenkleber zusammenkleben.

### Bespielen des ESP8266 mit dem Pflanzensensorprogramm

Es wird einen oder zwei Arbeitsplätze geben, an denen euer ESP8266 mit dem Fabmobil Pflanzensensor Programm bespielt wird. Geht dort hin und lasst euren Pflanzensensor aufspielen.

### Logdateien mitlesen

Du kannst die Logdateien deines Pflanzensensors mit deinem Laptop mitlesen. Dazu schließt du ihn per USB an deinen Laptop an, öffnest das Programm „Arduino IDE“ und dort unter „Werkzeuge“ den „serieller Monitor“. Du solltest dann das Log des Pflanzensensors sehen:

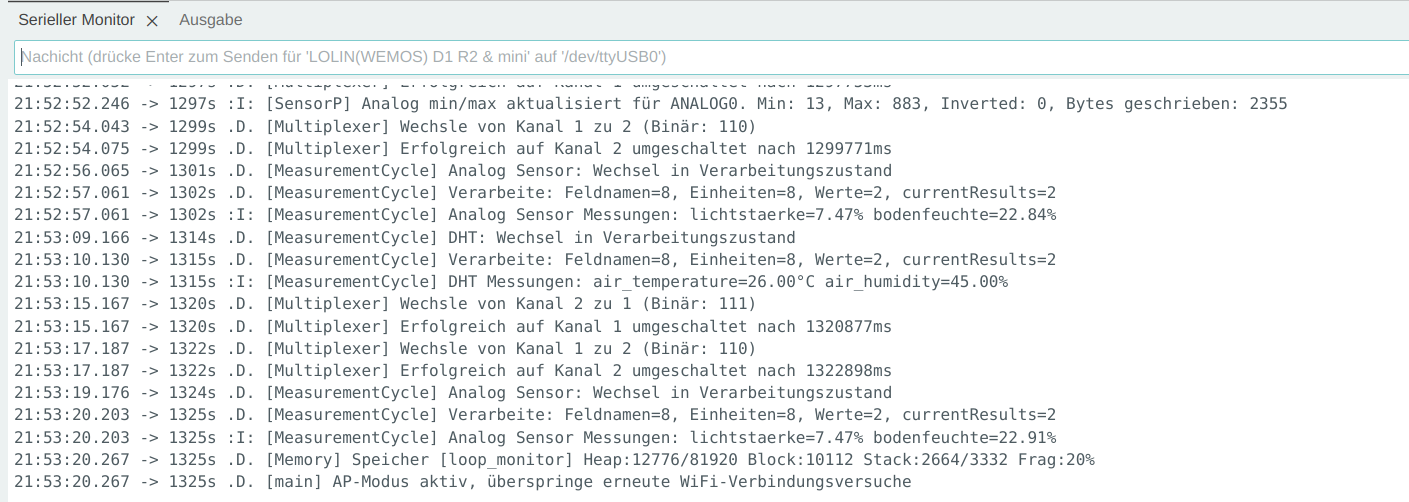
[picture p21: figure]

- Falls du nur unleserliche Zeichen erkennen kannst stimmt die Baudrate (Übertragungsgeschwindigkeit der Daten) nicht. Sie muss 115200 sein.
- Falls du gar keine Verbindung mit dem Pflanzensensor bekommst kann es sein, dass du den Port noch manuell festlegen musst: wähle „Werkzeuge“ in der Menüleiste und finde „Port“. Dort nimmst du den COM-Port mit der höheren Nummer. Falls das nicht funktioniert, versuche die anderen angebotenen COM-Ports durch

### Webinterface aufrufen

Finde die IP Adresse deines Pflanzensensors heraus. Er sollte mit dem Fabmobil WLAN verbunden sein und auf seinem Display seine IP Adresse anzeigen. Auch im Log wird sie regelmäßig angezeigt. Du musst sie in die Adressleiste deines Browsers einfügen:

Dann sollte sich die Pflanzensensorseite öffnen, sie sieht in etwa so aus:

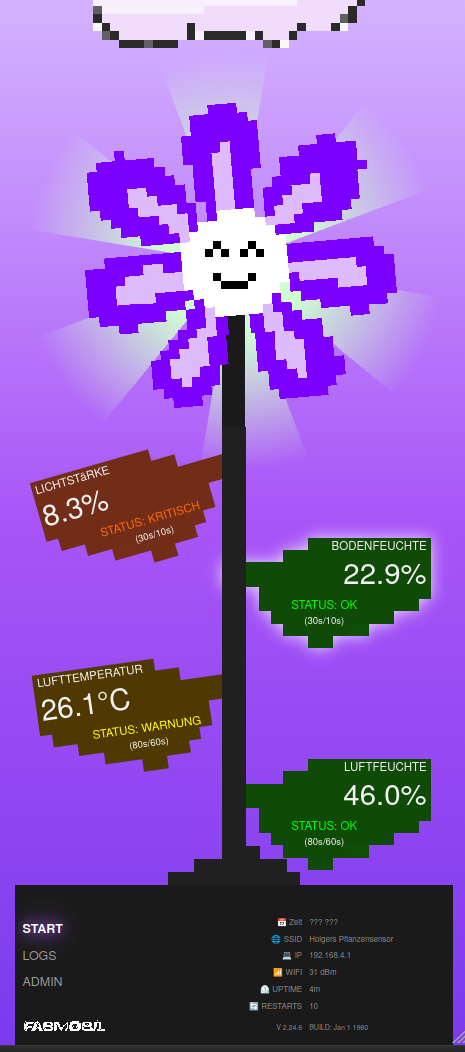
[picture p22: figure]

Schau dich um. Deine Pflanze zeigt die Werte der Sensoren an. Da diese noch nicht kalibriert sind, kann es sein das deine Pflanze traurig ist. Keine Sorge, wir ändern das gleich!

Die Funktionen der Pflanzensensor Webseite sind im Pflanzensensor Wiki erklärt. Lies dir folgende Seiten durch:

- Allgemeine Informationen zum Webinterface: https://github.com/Fabmobil/Pflanzensensor/wiki/Webinterface
- Informationen zur Geräteeinstellungsseite: https://github.com/Fabmobil/Pflanzensensor/wiki/Ger%C3%A4teeinstellungen
- Informationen zum Einstellen der Sensoren: https://github.com/Fabmobil/Pflanzensensor/wiki/Sensoreinstellungen
- Informationen zu den Displayeinstellungen: https://github.com/Fabmobil/Pflanzensensor/wiki/Displayeinstellungen

Mache dich mit der Webseite deines Pflanzensensors vertraut und versuche, Einstellungen zu ändern.

### Kalibrieren der Sensoren

Damit euer Bodenfeuchtesensor richtig funktioniert, müsst ihr ihn jetzt kalibrieren:

- Stecke den Bodenfeuchtesensor in sehr feuchte Erde. Achtung: Du solltest den Sensor immer gleich tief in die Erde stecken damit die Messung einigermaßen genau ist. Ein Sensor, der nur halb in der Erde steckt, wird dir andere Messwerte anzeigen als einer, der ganz in der Erde steckt. Ein weißer Strich auf dem Sensor kurz unterhalb des Gehäuses markiert die Stelle, bis zu der ihr den Sensor in die Erde stecken solltet.
- Geh auf die Adminseite deines Pflanzensensors, finde dort den Bodenfeuchte-Bereich und lese den aktueller absoluter Messwert ab. Dieser muss nun darunter bei Maximalwert eingetragen werden.
- Stecke den Bodenfeuchtesensor in sehr trockene Erde.
- Lies wieder den aktuellen absoluten Messwert ab und trage ihn diesmal bei Minimalwert ein.
  - Ggfs. kannst du auf den „MESSEN“ Button des Analogsensors drücken. Dann wird dein Pflanzensensor eine neue Messung dieses Sensors starten, sobald er Zeit dafür hat. Das kann allerdings immer noch ~10 Sekunden dauern
- Deine Änderungen werden automatisch gespeichert. Achte auf die Bestätigungsmitteilung oben rechts wenn du Änderungen vornimmst:
- Jetzt ist dein Bodenfeuchtesensor kalibriert. Falls du allerdings später zu Hause andere Erde hast kann es sein, dass du die Kalibrierung dort noch einmal wiederholen musst.
- Auch dein Helligkeitssensor kann kalibriert werden: Für den Minimalwert bedeckst du ihn damit es ganz dunkel ist. Für den Maximalwert hältst du ihn direkt in die Sonne.

### Einstellen der Grenzen für die LED Ampel

Die Grenzwerte der LED Ampel für die unterschiedlichen Sensoren können auf der Adminseite deines Pflanzensensors eingestellt werden:

Diese Schwellwerte sind folgendermaßen definiert:

Abhängig davon, was die Pflanze die du mit dem Sensor überwachen willst für Bedürftnisse hat, stellst du jetzt die Skale für die unterschiedlichen Sensoren ein.

### Update der Software

Wenn es eine neue Version der Pflanzensensorsoftware gibt kannst du deinen Pflanzensensor auch von zu Hause aktualisieren. Wie das geht steht hier: https://github.com/Fabmobil/Pflanzensensor/wiki/Update
Probiere es gern aus damit du nachfragen kannst wenn du etwas nicht verstehst bevor du zu Hause daran scheitest und niemanden fragen kannst!

## Wie weiter?

Jede*r die/der möchte bekommt einen Pflanzensensor mit nach Hause. Im besten Fall weißt du nun, wie du ihn konfigurieren und einsetzen kannst.
Unter https://www.github.com/fabmobil/pflanzensensor findet ihr die Dokumentation und den Quellcode zu eurem Sensor. Dort werden auch Aktualisierungen des Pflanzensensor-Programms veröffentlicht. Falls ihr in ein paar Wochen vergessen habt, wir ihr das Pflanzensensor Programm flashen könnt, steht das dort auch beschrieben.

Falls ihr Fragen oder Anregungen habt könnt ihr uns auch gern per Email kontaktieren: pflanzensensor@fabmobil.org

Vielleicht findet ihr den Pflanzensensor ja aber auch doof und wollt lieber ganz andere Sachen mit eurem WLAN-fähigen Mikroprozessor machen? Kein Problem: zieht ihn einfach aus dem PCB raus und widmet ihn um. Das Internet ist voll mit Tutorials und Anleitungen, wenn ihr Inspiration braucht könnt ihr zum Beispiel hier mal schmökern: https://polluxlabs.net/esp8266-projekte/

Viel Spaß❣️

# Verwendete Programme und Links

## Calliope

- Calliope Lernkarten aus dem Fabmobil (https://fabmobil.org/tutorials/lernkarten-calliope-mini)
- Calliope Online Editor (https://makecode.calliope.cc/)
- Einführungs Tutorial auf Youtube (https://www.youtube.com/watch?v=76ryLoWfYhs)

## Pflanzensensor

- Arduino IDE (https://www.arduino.cc/en/software)
- Pflanzensensor Quellcode und Erklärungen (https://github.com/Fabmobil/Pflanzensensor)
- Anleitungen im Pflanzensensor Wiki:
  - Pflanzensensor konfigurieren und bespielen (https://github.com/Fabmobil/Pflanzensensor/wiki/Update)
  - Erklärungen zum Webinterface (https://github.com/Fabmobil/Pflanzensensor/wiki/Webinterface)

## Fabmobil und Silicon Saxony

- 💜 Fabmobil Homepage (https://fabmobil.org/) 💜
- 🩵 Silicon Saxony (https://silicon-saxony.de/) 🩵
- 🧡 Bosch (https://www.bosch.de/) 🧡
- 💚 Global Foundries (https://gf.com/) 💚
- 🩷 Infineon (https://www.infineon.com/) 🩷
- 🩶 Xfab (https://www.xfab.com/) 🩶

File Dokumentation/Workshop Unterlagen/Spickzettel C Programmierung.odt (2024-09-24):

# Spickzettel C/C++ Programmierung

## Grundstruktur eines Arduino-Programms

void setup() {

// Wird einmal beim Start ausgeführt

// Hier initialisieren wir Pins, Serial, etc.

}

void loop() {

// Wird endlos wiederholt

// Hier kommt der Hauptcode hin

}

## Variablen und Datentypen

Calliope | C/C++ | Erklärung
Zahl | int zahl = 42; | Ganze Zahlen, typischerweise -32768 bis 32767
Kommazahl | float komma = 3.14; | Zahlen mit Nachkommastellen
Wahr/Falsch | bool wahr = true; | Logische Werte (true oder false)
Text | String text = "Hallo"; | Zeichenketten

Zusätzliche wichtige Datentypen:

- long: Für größere ganze Zahlen
- double: Für präzisere Kommazahlen
- char: Für einzelne Zeichen

## Ein- und Ausgabe

Calliope | C/C++ (Arduino) | Erklärung

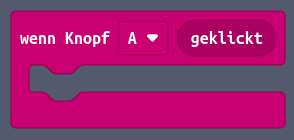
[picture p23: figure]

| digitalRead(BUTTON_A) == LOW | Prüft, ob ein Knopf gedrückt ist
| digitalWrite(LED_BUILTIN, LOW); | Schaltet die eingebaute LED ein (invertiert)
| digitalWrite(LED_BUILTIN, HIGH); | Schaltet die eingebaute LED aus (invertiert)
| Serial.println(zahl); | Gibt eine Zahl über Serial aus
| Serial.println("hi!"); | Gibt Text über Serial aus
Pin 0 als Eingang | pinMode(0, INPUT); | Konfiguriert Pin 0 als Eingang
Pin 1 als Ausgang | pinMode(1, OUTPUT); | Konfiguriert Pin 1 als Ausgang
| int wert = analogRead(A0); | Liest einen analogen Wert (0-1023)

Wichtig für Serial:

void setup() {

Serial.begin(9600); // Startet die serielle Kommunikation

}

## Kontrollstrukturen

### Wenn-Dann (If-Else)

#### Calliope

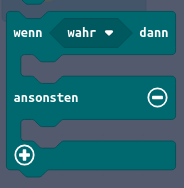
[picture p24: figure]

#### C/C++

if (Bedingung) {

// Anweisungen wenn Bedingung wahr

} else {

// Anweisungen wenn Bedingung falsch

}

##### Beispiel

if (temperatur > 25) {

digitalWrite(VENTILATOR_PIN, HIGH);

} else {

digitalWrite(VENTILATOR_PIN, LOW);

}

### Schleifen

#### Calliope “x-Mal wiederholen”

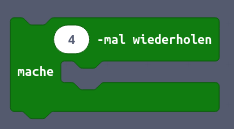
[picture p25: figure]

#### C/C++ “x-Mal wiederholen”

for (int i = 0; i < 5; i++) {

// Anweisungen

}

##### Beispiel

for (int i = 0; i < 5; i++) {

digitalWrite(LED_PIN, HIGH);

delay(100);

digitalWrite(LED_PIN, LOW);

delay(100);

}

#### Calliope “dauerhaft”

#### C/C++ “dauerhaft”

while (true) {

// Anweisungen

}

##### Beispiel

while (digitalRead(BUTTON_PIN) == HIGH) {

// Führe Aktionen aus, solange der Knopf gedrückt ist

}

## Funktionen

#### Calliope

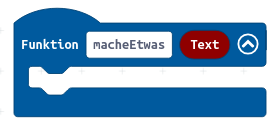
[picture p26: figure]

#### C/C++

void meineFunktion() {

// Anweisungen

}

##### Beispiel

Funktion mit Rückgabewert und Parametern:

int addiere(int a, int b) {

return a + b;

}

## Operatoren

Operation | C/C++ | Beispiel
Gleich | == | if (a == b) { ... }
Ungleich | != | if (a != b) { ... }
Größer | > | if (a > b) { ... }
Größer gleich | >= | if (a >= b) { ... }
Kleiner | < | if (a < b) { ... }
Kleiner gleich | <= | if (a <= b) { ... }
Und | && | if (a && b) { ... }
Oder | || | if (a || b) { ... }
Nicht | ! | if (!a) { ... }

## Wichtige Arduino-Funktionen

- delay(ms): Pausiert das Programm für die angegebene Zeit in Millisekunden
  delay(1000); // Wartet 1 Sekunde
- random(max) oder random(min, max): Erzeugt eine Zufallszahl
  int zufallszahl = random(1, 101); // Zufallszahl zwischen 1 und 100

## Arrays und Strings

### Arrays

int zahlen[5] = {1, 2, 3, 4, 5};

int ersteZahl = zahlen[0]; // Zugriff auf das erste Element (Index 0)

### Strings

String name = "Alice";

int laenge = name.length(); // Länge des Strings

## Tipps für C/C++ Programmierung

- Jede Anweisung endet mit einem Semikolon: ;
- Blöcke werden mit geschweiften Klammern { } umschlossen
- Kommentare
  - Einzeilig: // Kommentar
  - Mehrzeilig: /* mehrzeiliges Kommentar */
- Variablen müssen vor der Verwendung deklariert werden
- Groß- und Kleinschreibung ist wichtig (case-sensitive)
- Verwende aussagekräftige Variablen- und Funktionsnamen
- Einrückung verbessert die Lesbarkeit (wird vom Compiler ignoriert)
- Nutze Konstanten für unveränderliche Werte: const int LED_PIN = 13;
- Debuggen mit Serial.print():

Serial.print("Debug: ");

Serial.println(variable);

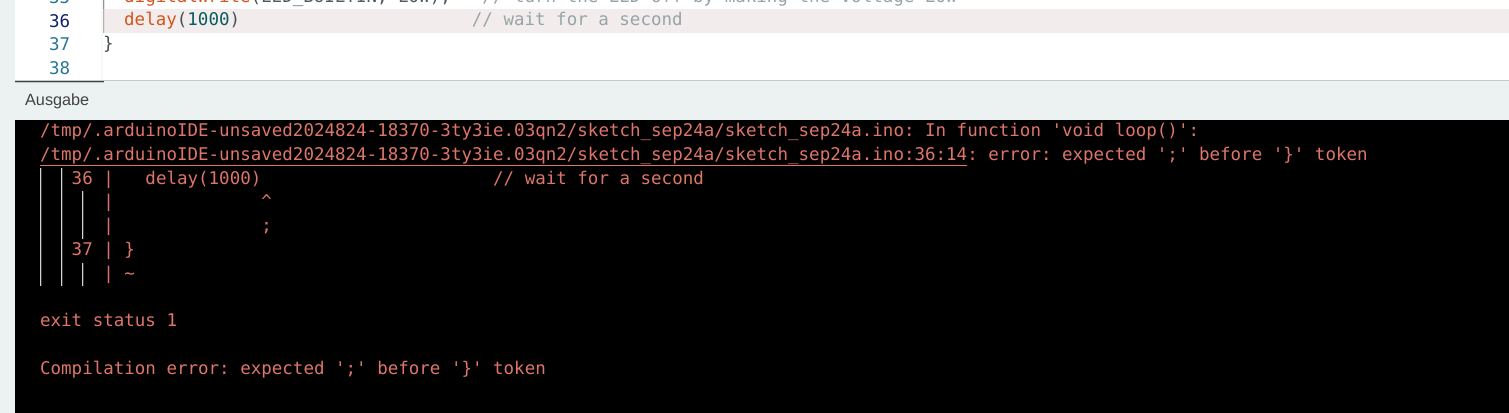
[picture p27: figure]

- Bei Fehlern im Code zeigt die Arduino IDE Fehlermeldungen an die, mit ein wenig Erfahrung, durchaus hilfreich sind. Leider sind sie auf Englisch. Hier wurde das ";" hinter dem delay(1000) vergessen und die Arduino IDE weist darauf hin
- Das Internet ist voll von Arduino Tutorials, sowohl als Video als auch als Text und auch in der Fabmobil-Bibliothek gibt es einige Bücher zum Thema.


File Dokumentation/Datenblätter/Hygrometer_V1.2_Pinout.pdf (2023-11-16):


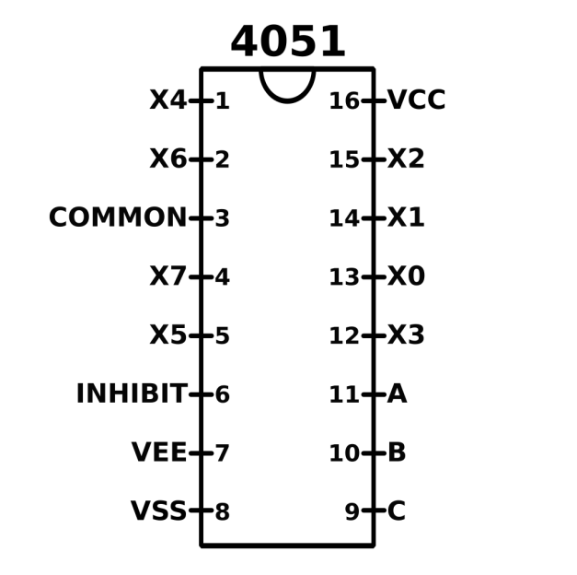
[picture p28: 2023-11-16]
Dokumentation/Datenblätter/4051 analog multiplexer pinout.png

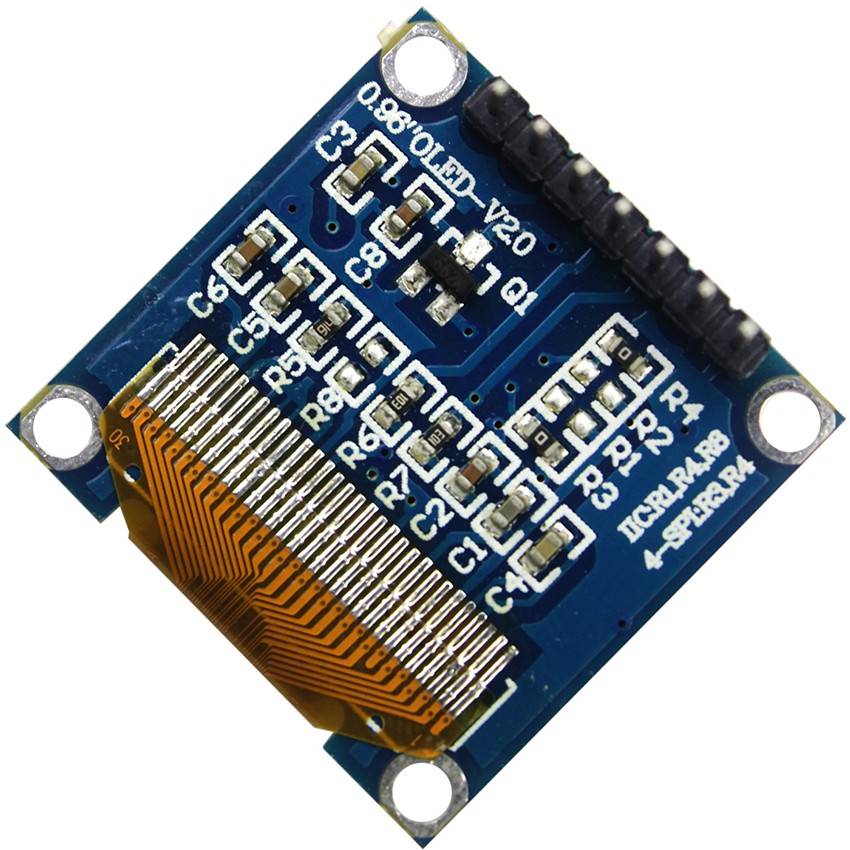
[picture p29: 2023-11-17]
Dokumentation/Datenblätter/ssd1306-oled.jpg

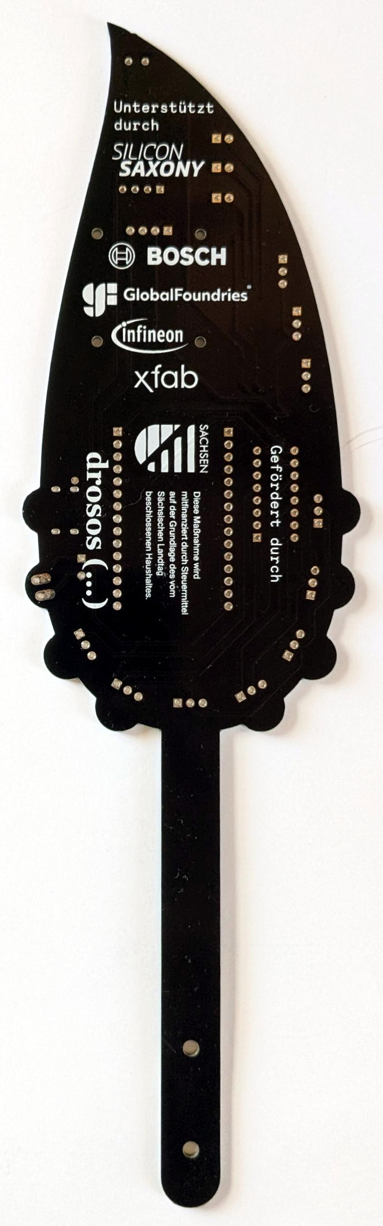
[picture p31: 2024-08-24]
Dokumentation/Bilder/PCB_hinten.jpeg

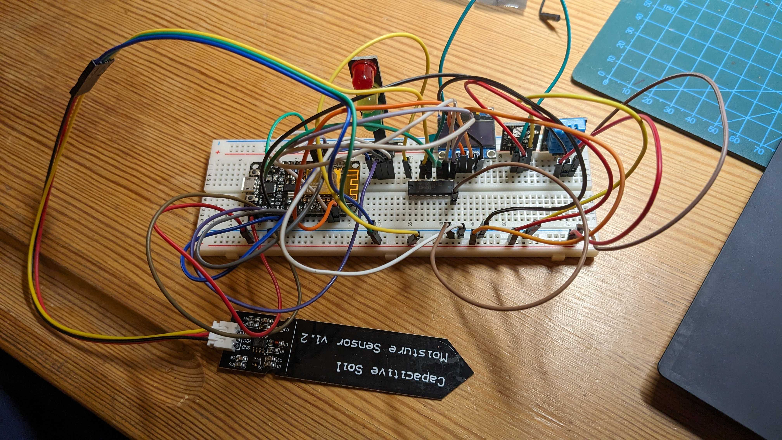
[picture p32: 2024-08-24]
Dokumentation/Bilder/Pflanzensensor_Breadboard.jpg

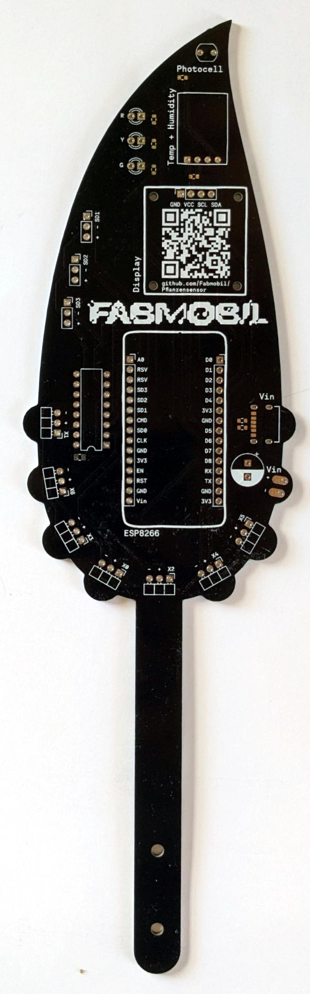
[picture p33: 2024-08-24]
Dokumentation/Bilder/PCB_vorn.jpeg

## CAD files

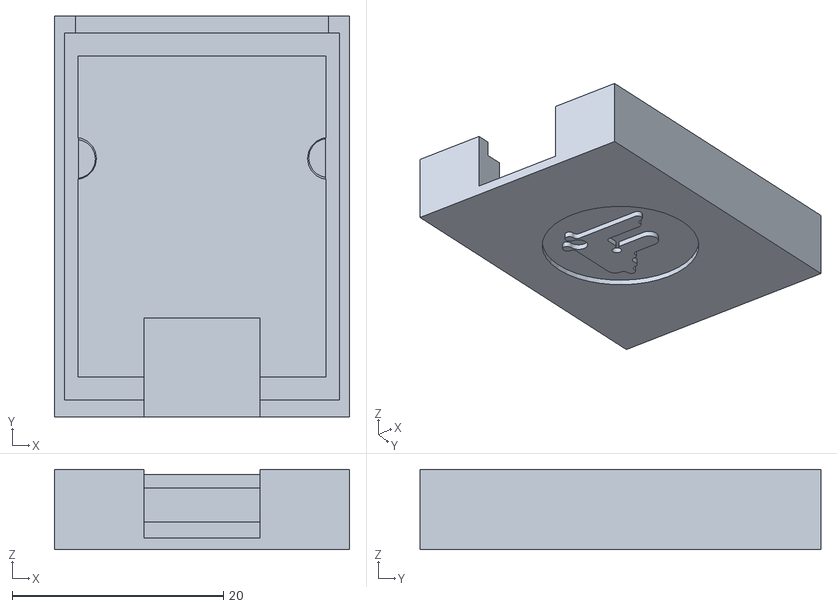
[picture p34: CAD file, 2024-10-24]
Dokumentation/3D Modelle/Bodenfeuchtesensor_Gehäuse_oben.stl
28.0 x 38.0 x 7.60

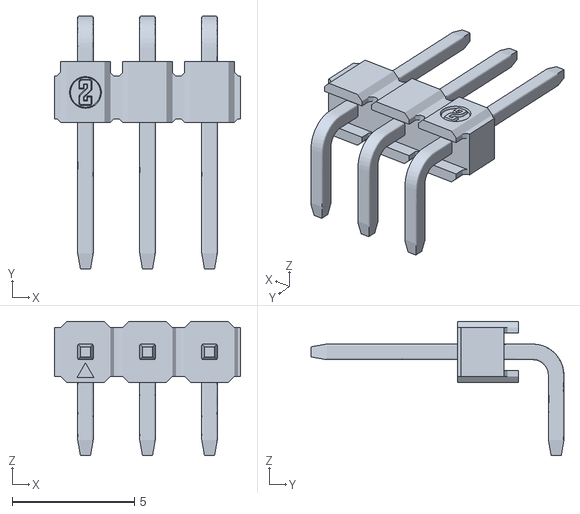
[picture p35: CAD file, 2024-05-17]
Dokumentation/3D Modelle/AnalogPINs.stl
7.62 x 10.4 x 5.50

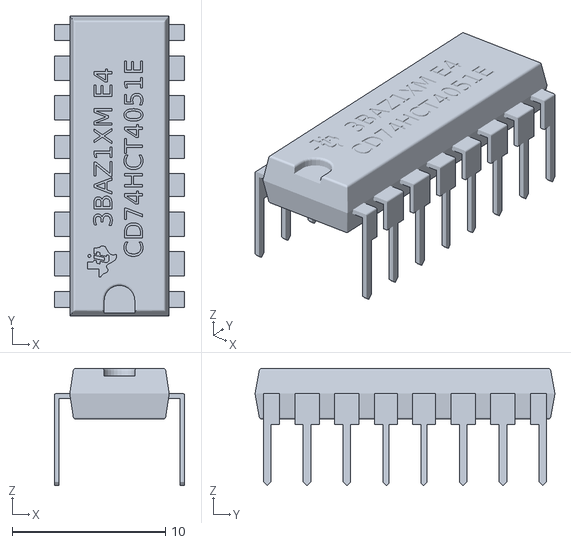
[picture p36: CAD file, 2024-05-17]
Dokumentation/3D Modelle/Multiplexer_4051.stl
8.52 x 19.6 x 7.65

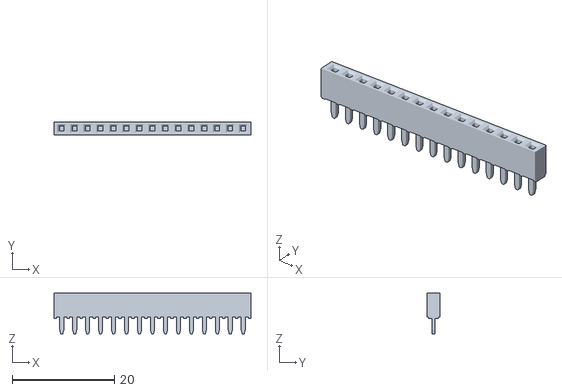
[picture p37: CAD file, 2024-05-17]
Dokumentation/3D Modelle/15-Pin Header - Female - 2.54mm.stl
38.6 x 2.50 x 8.00

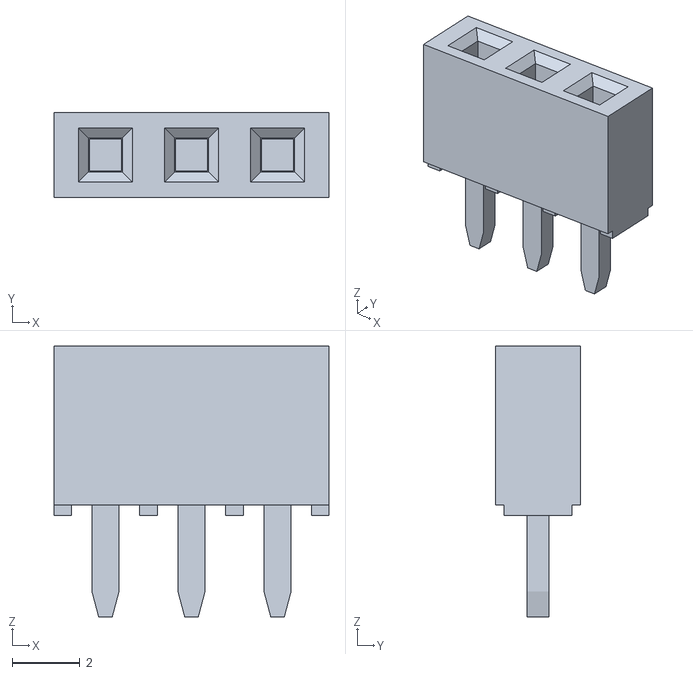
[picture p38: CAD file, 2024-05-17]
Dokumentation/3D Modelle/3-Pin Header - Female - 2.54mm.stl
8.12 x 2.50 x 8.00

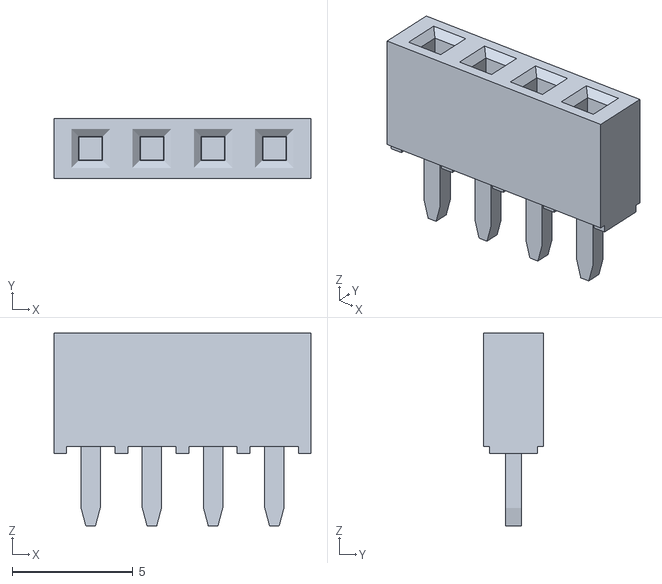
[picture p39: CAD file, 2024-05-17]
Dokumentation/3D Modelle/4-Pin Header - Female - 2.54mm.stl
10.7 x 2.50 x 8.00

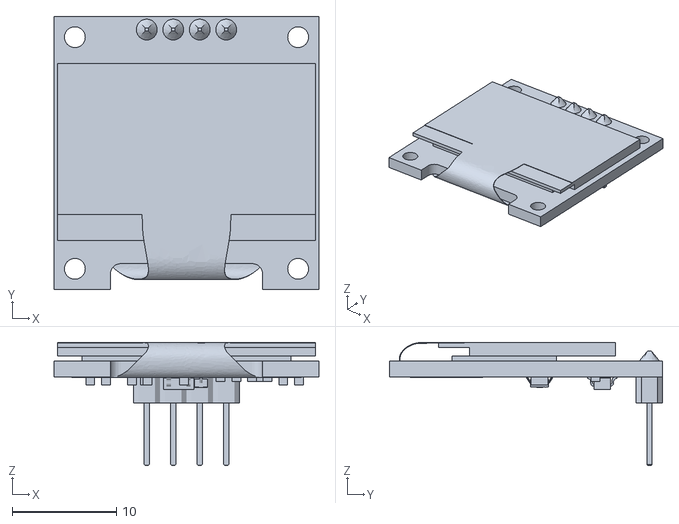
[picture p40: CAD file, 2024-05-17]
Dokumentation/3D Modelle/SSD1306.stl
25.4 x 26.2 x 11.8

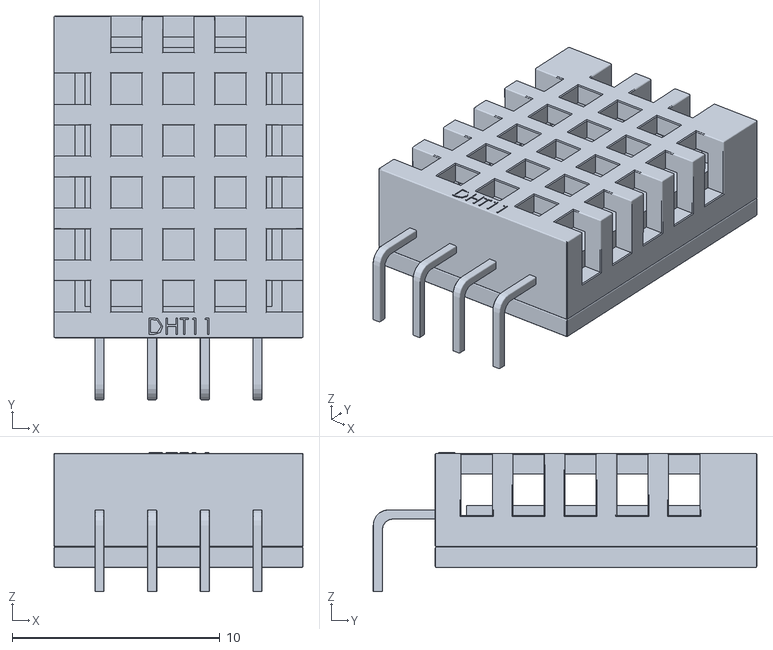
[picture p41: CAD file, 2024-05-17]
Dokumentation/3D Modelle/DHT11.stl
12.0 x 18.5 x 6.72

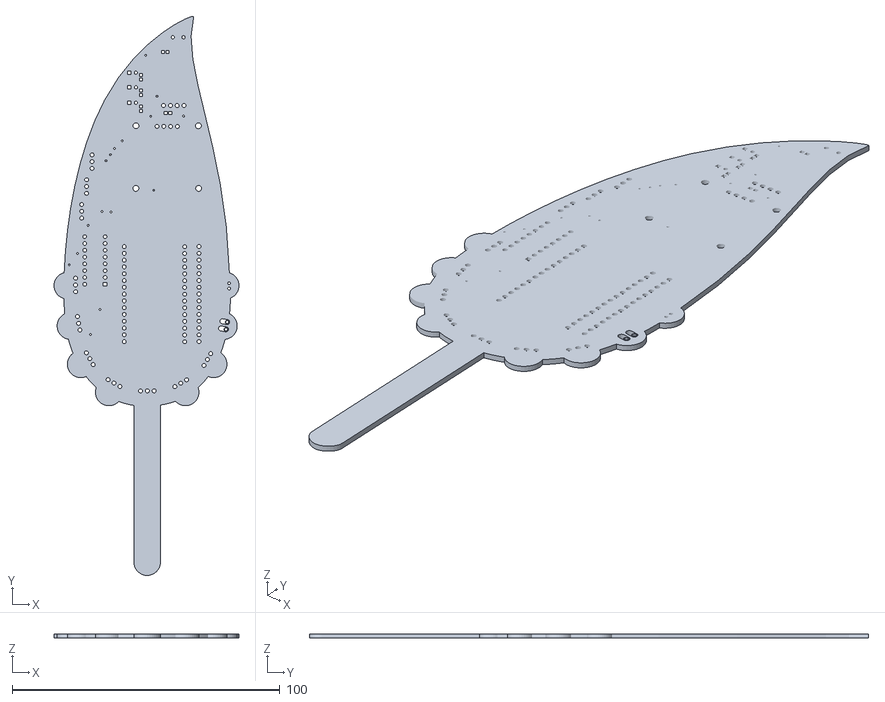
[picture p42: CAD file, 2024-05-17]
Dokumentation/3D Modelle/Leiterplatte.stl
69.1 x 208.8 x 1.50

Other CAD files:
Dokumentation/3D Modelle/Bodenfeuchtesensor_Gehäuse_unten.stl

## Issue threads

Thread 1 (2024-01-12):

Multiplexer auf 3 Eingänge erweitern

Fabmobil, 2024-01-12:
Wir haben uns entschieden alle 8 möglichen Analogsensoren ansteuern zu können. Die Software spricht aber erst mit max. 4. Außerdem muss sie so geändert werden, dass der Default ist, dass b und c am Multiplexer immer auf 1 stehen, damit die LEDs ausbleiben

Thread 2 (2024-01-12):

Anpassungen in der Adminseite für 7 Analogsensoren

Fabmobil, 2024-01-12:
.. naheliegend wären folgende zwei Möglichkeiten:

    7 Bodenfeuchtesensoren in 7 Töpfen
    4 Bodenfeuchtesensoren und 4 Helligkeitssensoren

Beide Versionen sollten auswählbar und entsprechend konfigurierbar sein

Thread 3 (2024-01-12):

ESP rebootet manchmal wenn der Webserver aufgerufen wird

Fabmobil, 2024-01-12:
.. Ursache unklar

```
--------------- CUT HERE FOR EXCEPTION DECODER ---------------

Exception (29):
epc1=0x4000df64 epc2=0x00000000 epc3=0x00000000 excvaddr=0x00000000 depc=0x00000000

>>>stack>>>

ctx: sys
sp: 3fffec70 end: 3fffffb0 offset: 0150
3fffedc0:  4023a5d3 3ffef540 00000002 4023a568
3fffedd0:  00000002 4023a50f 00000002 40239664
3fffede0:  4023968d 3fffee90 3ffef540 00000016
3fffedf0:  402370ec 3fffee90 3ffef3e8 3ffeedb0
3fffee00:  3ffec5f8 3fffee90 3fffee90 40226038
3fffee10:  6d6d6f54 0db90079 4010371a 00000100
3fffee20:  3ffeb2f4 7fffffff 00000000 00000001
3fffee30:  40233449 00000080 4000050c 3fffc278
3fffee40:  ffffffda 3ffeeefc 3ffec608 3ffef540
3fffee50:  3ffee4b8 0000003a 00000000 40237de7
3fffee60:  00000000 3fff10fc ffffffda 00000000
3fffee70:  00000000 3ffef540 0000001e ffffffff
3fffee80:  40000f58 00000000 00000020 00000000
3fffee90:  00000000 11110606 00640100 00000044
3fffeea0:  3ffec61c 00000109 3ffec630 3ffec610
3fffeeb0:  3ffec636 3ffec61c 3ffec623 3ffec648
3fffeec0:  00000000 00000000 3ffec64e 3ffec70b
3fffeed0:  3ffec664 3ffec680 00000000 00000000
3fffeee0:  00000000 00000000 0000003a 00000000
3fffeef0:  3fff13a4 40237856 3ffee4b8 3fff10fc
3fffef00:  00000000 3ffef540 3ffee4b8 3ffec5f8
3fffef10:  3ffec5f8 00000131 00000000 0000003a
3fffef20:  00000000 3ffec602 4024af2f 3ffee4b8
3fffef30:  3ffec5ec 3fffdcc0 3ffeab30 3ffeab30
3fffef40:  00000080 3ffee4b8 00000002 00000000
3fffef50:  4024a7f3 3fffdab0 00000000 00000004
3fffef60:  3ffeab30 40000f49 3fffdab0 40000f49
3fffef70:  40000e19 0006556f bff00000 0000bfff
3fffef80:  00000005 aa55aa55 000000c1 40105891
3fffef90:  40105897 bff00000 0000bfff 31315448
3fffefa0:  4010000d bff00000 0006556f 401000ab
3fffefb0:  4023f764 3fffef4c 4023f715 3ffffce8
3fffefc0:  3fffffd0 00000000 00000000 feefeffe
3fffefd0:  feefeffe feefeffe feefeffe feefeffe
3fffefe0:  feefeffe feefeffe feefeffe feefeffe
3fffeff0:  feefeffe feefeffe feefeffe feefeffe
3ffff000:  feefeffe feefeffe feefeffe feefeffe
3ffff010:  feefeffe feefeffe feefeffe feefeffe
3ffff020:  feefeffe feefeffe feefeffe feefeffe
3ffff030:  feefeffe feefeffe feefeffe feefeffe
3ffff040:  feefeffe feefeffe feefeffe feefeffe
3ffff050:  feefeffe feefeffe feefeffe feefeffe
3ffff060:  feefeffe feefeffe feefeffe feefeffe
3ffff070:  feefeffe feefeffe feefeffe feefeffe
3ffff080:  feefeffe feefeffe feefeffe feefeffe
3ffff090:  feefeffe feefeffe feefeffe feefeffe
3ffff0a0:  feefeffe feefeffe feefeffe feefeffe
3ffff0b0:  feefeffe feefeffe feefeffe feefeffe
3ffff0c0:  feefeffe feefeffe feefeffe feefeffe
3ffff0d0:  feefeffe feefeffe feefeffe feefeffe
3ffff0e0:  feefeffe feefeffe feefeffe feefeffe
3ffff0f0:  feefeffe feefeffe feefeffe feefeffe
3ffff100:  feefeffe feefeffe feefeffe feefeffe
3ffff110:  feefeffe feefeffe feefeffe feefeffe
3ffff120:  feefeffe feefeffe feefeffe feefeffe
3ffff130:  feefeffe feefeffe feefeffe feefeffe
3ffff140:  feefeffe feefeffe feefeffe feefeffe
3ffff150:  feefeffe feefeffe feefeffe feefeffe
3ffff160:  feefeffe feefeffe feefeffe feefeffe
3ffff170:  feefeffe feefeffe feefeffe feefeffe
3ffff180:  feefeffe feefeffe feefeffe feefeffe
3ffff190:  feefeffe feefeffe feefeffe feefeffe
3ffff1a0:  feefeffe feefeffe feefeffe feefeffe
3ffff1b0:  feefeffe feefeffe feefeffe feefeffe
3ffff1c0:  feefeffe feefeffe feefeffe feefeffe
3ffff1d0:  feefeffe feefeffe feefeffe feefeffe
3ffff1e0:  feefeffe feefeffe feefeffe feefeffe
3ffff1f0:  feefeffe feefeffe feefeffe feefeffe
3ffff200:  feefeffe feefeffe feefeffe feefeffe
3ffff210:  feefeffe feefeffe feefeffe feefeffe
3ffff220:  feefeffe feefeffe feefeffe feefeffe
3ffff230:  feefeffe feefeffe feefeffe feefeffe
3ffff240:  feefeffe feefeffe feefeffe feefeffe
3ffff250:  feefeffe feefeffe feefeffe feefeffe
3ffff260:  feefeffe feefeffe feefeffe feefeffe
3ffff270:  feefeffe feefeffe feefeffe feefeffe
3ffff280:  feefeffe feefeffe feefeffe feefeffe
3ffff290:  feefeffe feefeffe feefeffe feefeffe
3ffff2a0:  feefeffe feefeffe feefeffe feefeffe
3ffff2b0:  feefeffe feefeffe feefeffe feefeffe
3ffff2c0:  feefeffe feefeffe feefeffe feefeffe
3ffff2d0:  feefeffe feefeffe feefeffe feefeffe
3ffff2e0:  feefeffe feefeffe feefeffe feefeffe
3ffff2f0:  feefeffe feefeffe feefeffe feefeffe
3ffff300:  feefeffe feefeffe feefeffe feefeffe
3ffff310:  feefeffe feefeffe feefeffe feefeffe
3ffff320:  feefeffe feefeffe feefeffe feefeffe
3ffff330:  feefeffe feefeffe feefeffe feefeffe
3ffff340:  feefeffe feefeffe feefeffe feefeffe
3ffff350:  feefeffe feefeffe feefeffe feefeffe
3ffff360:  feefeffe feefeffe feefeffe feefeffe
3ffff370:  feefeffe feefeffe feefeffe feefeffe
3ffff380:  feefeffe feefeffe feefeffe feefeffe
3ffff390:  feefeffe feefeffe feefeffe feefeffe
3ffff3a0:  feefeffe feefeffe feefeffe feefeffe
3ffff3b0:  feefeffe feefeffe feefeffe feefeffe
3ffff3c0:  feefeffe feefeffe feefeffe feefeffe
3ffff3d0:  feefeffe feefeffe feefeffe feefeffe
3ffff3e0:  feefeffe feefeffe feefeffe feefeffe
3ffff3f0:  feefeffe feefeffe feefeffe feefeffe
3ffff400:  feefeffe feefeffe feefeffe feefeffe
3ffff410:  feefeffe feefeffe feefeffe feefeffe
3ffff420:  feefeffe feefeffe feefeffe feefeffe
3ffff430:  feefeffe feefeffe feefeffe feefeffe
3ffff440:  feefeffe feefeffe feefeffe feefeffe
3ffff450:  feefeffe feefeffe feefeffe feefeffe
3ffff460:  feefeffe feefeffe feefeffe feefeffe
3ffff470:  feefeffe feefeffe feefeffe feefeffe
3ffff480:  feefeffe feefeffe feefeffe feefeffe
3ffff490:  feefeffe feefeffe feefeffe feefeffe
3ffff4a0:  feefeffe feefeffe feefeffe feefeffe
3ffff4b0:  feefeffe feefeffe feefeffe feefeffe
3ffff4c0:  feefeffe feefeffe feefeffe feefeffe
3ffff4d0:  feefeffe feefeffe feefeffe feefeffe
3ffff4e0:  feefeffe feefeffe feefeffe feefeffe
3ffff4f0:  feefeffe feefeffe feefeffe feefeffe
3ffff500:  feefeffe feefeffe feefeffe feefeffe
3ffff510:  feefeffe feefeffe feefeffe feefeffe
3ffff520:  feefeffe feefeffe feefeffe feefeffe
3ffff530:  feefeffe feefeffe feefeffe feefeffe
3ffff540:  feefeffe feefeffe feefeffe feefeffe
3ffff550:  feefeffe feefeffe feefeffe feefeffe
3ffff560:  feefeffe feefeffe feefeffe feefeffe
3ffff570:  feefeffe feefeffe feefeffe feefeffe
3ffff580:  feefeffe feefeffe feefeffe feefeffe
3ffff590:  feefeffe feefeffe feefeffe feefeffe
3ffff5a0:  feefeffe feefeffe feefeffe feefeffe
3ffff5b0:  feefeffe feefeffe feefeffe feefeffe
3ffff5c0:  feefeffe feefeffe feefeffe feefeffe
3ffff5d0:  feefeffe feefeffe feefeffe feefeffe
3ffff5e0:  feefeffe feefeffe feefeffe feefeffe
3ffff5f0:  feefeffe feefeffe feefeffe feefeffe
3ffff600:  feefeffe feefeffe feefeffe feefeffe
3ffff610:  feefeffe feefeffe feefeffe feefeffe
```

pippcat, 2024-02-15:
Eventuell gefixt mit mutex?: https://github.com/Fabmobil/Pflanzensensor/commit/5c5814261fc2e5f9e86c397d9c24937d01003539

Closed 2024-02-15.

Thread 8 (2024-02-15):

ArduinoIDE >V2 lässt kein LittleFS data upload zu

pippcat, 2024-02-15:
- Das Hochladen der LittleFS Datenpartition funktioniert OOTB nur mit der Arduino IDE V1.8. Versionen >2 können das nicht.
- Oder eventuell doch, mit diesem Plugin: https://github.com/earlephilhower/arduino-littlefs-upload ?
- Ansonsten gibt es hier etwas dazu zu lesen: https://forum.arduino.cc/t/littlefs-data-upload-in-arduino-2-x-x/1174393/2
- Auf den Laptops im Fabmobil ist V2.3.1 installiert.
- Zur Show muss das funktionieren
- die Doku muss entsprechend angepasst werden.

Fabmobil, 2024-08-23:
Funktioniert mit diesem Plugin wie beschrieben: https://github.com/earlephilhower/arduino-littlefs-upload

Closed 2024-08-23.

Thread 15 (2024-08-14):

Mehr Werte für den Webhook

pippcat, 2024-08-14:
Dem Webhook JSON sollte hinzugefügt werden:

- die Frequenz von Alarm und Ping
- den Sensoren ein bool, ob der Alarm gesetzt ist oder nicht

pippcat, 2024-08-21:
Frequenzen werden seit 20603206ae8ba8c51b0771bbfae18800122c06f7 übertragen, Alarm aktiv oder nicht fehlt noch.

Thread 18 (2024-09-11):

WIFI Daten über Webinterface ändern

pippcat, 2024-09-11:
Es wäre gut, wenn die Wifidaten über das Webinterface geändert werden können. Das hat natürlich die Gefahr, dass man die Verbindung zum Webinterface verkonfiguriert. Deshalb sollten vielleicht nur die Daten geändert werden können, die gerade nicht verwendet werden?

pippcat, 2024-09-20:
Hinzugefügt mit 2ac5502b74340428fce41b1941cf50bd66a5ae57

Closed 2024-09-20.

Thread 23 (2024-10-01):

Neues Modul: Magnetventil

pippcat, 2024-10-01:
Ein Modul um Pflanzen über ein Magnetventil bewässern zu können wäre nice.

Inspiration hier: https://crycode.de/diy-automatisches-bewaesserungssystem

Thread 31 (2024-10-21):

Steckerleisten des PCBs überarbeiten

pippcat, 2024-10-21:
Für die nächste Bestellung sollte beiderseitig eine Doppelsteckerleiste verbaut werden:
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
Der jetzige Abstand soll der innere Abstand sein. Dann sollten alle 3 unterschiedlichen PCB-Breiten reinpassen

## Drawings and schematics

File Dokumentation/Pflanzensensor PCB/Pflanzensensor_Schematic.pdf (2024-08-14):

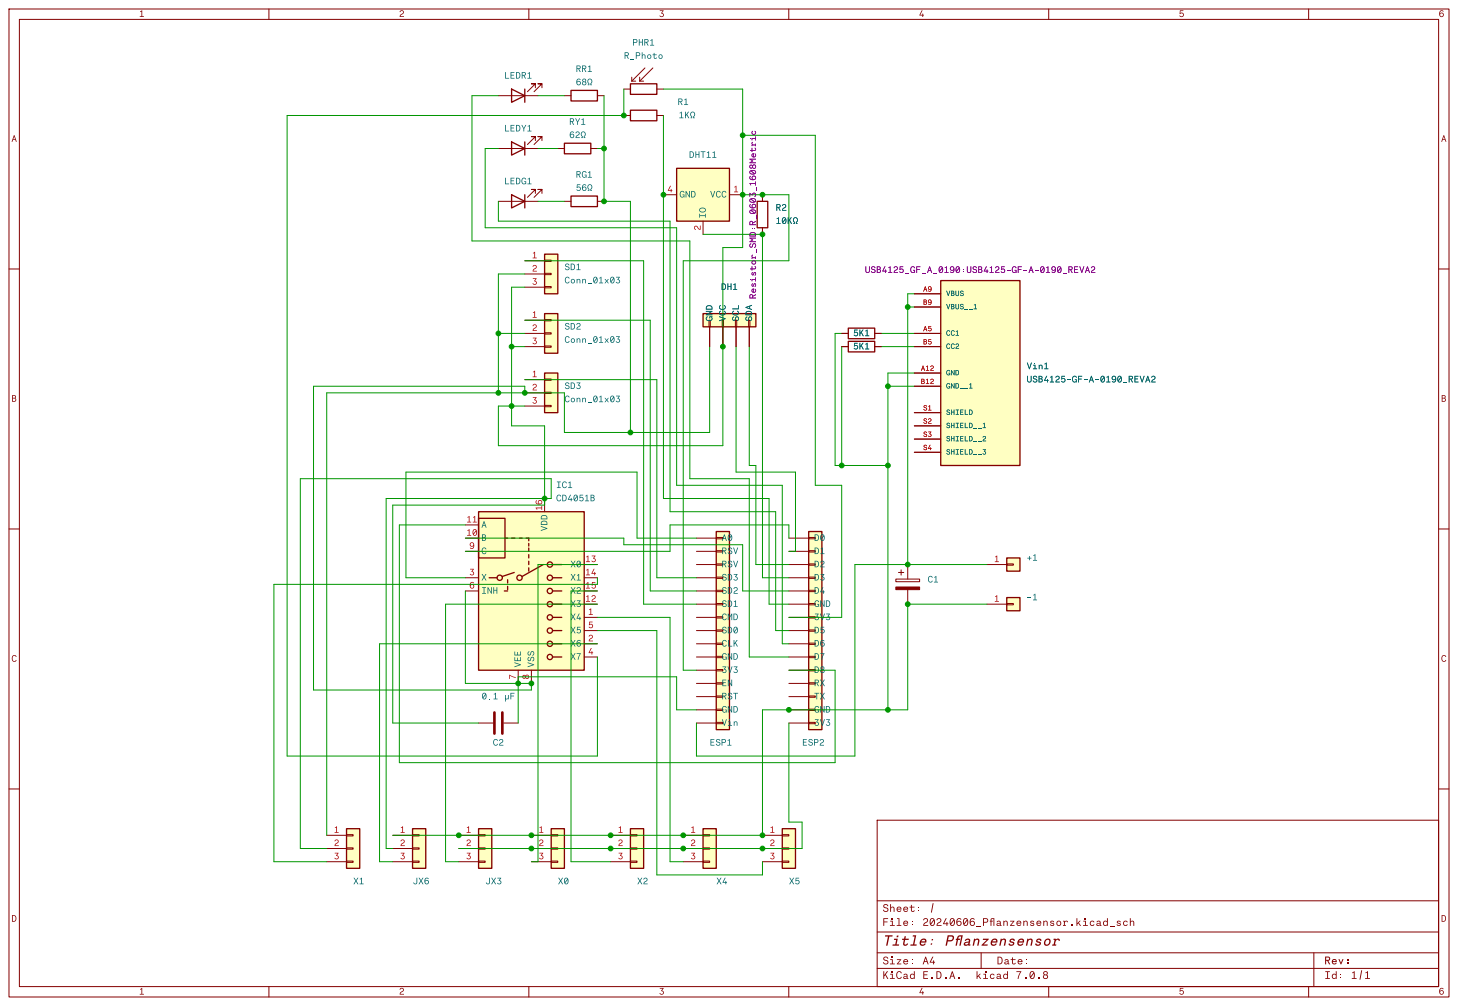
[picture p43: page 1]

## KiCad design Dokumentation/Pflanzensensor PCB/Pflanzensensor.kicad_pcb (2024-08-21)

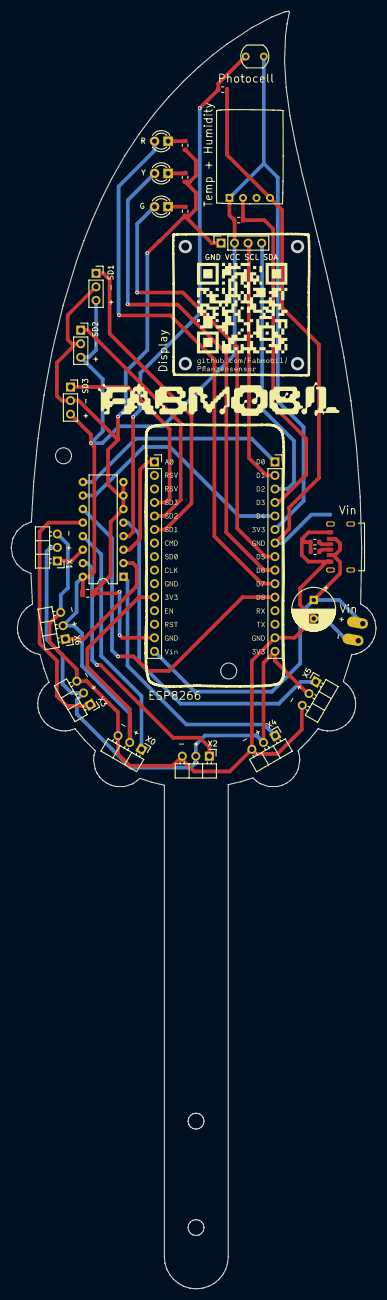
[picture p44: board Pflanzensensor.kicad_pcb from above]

Board: 2 copper layers, 68.5 x 239.9 mm, 32 parts (0 on the bottom side), 32 nets.

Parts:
+: Conn_01x01; SolderWirePad_1x01_SMD_1x2mm
-: SolderWirePad_1x01_SMD_1x2mm
C1: C_Polarized; CP_Radial_D8.0mm_P3.50mm
C2: 0.1 µF; C_0805_2012Metric
DH1: Conn_01x04; PinSocket_1x04_P2.54mm_Vertical
DHT11: VCC SIG – GND; Aosong_DHT11_5.5x12.0_P2.54mm
ESP1, ESP2: Conn_01x15; PinSocket_1x15_P2.54mm_Vertical
IC1: CD4051B; DIP-16_W7.62mm
LEDG1: Green 568nm; LED_D3.0mm
LEDR1: Red 617nm; LED_D3.0mm
LEDY1: 588nm; LED_D3.0mm
PHR1: R_Photo; R_LDR_5.1x4.3mm_P3.4mm_Vertical
R1: 1KΩ; R_0603_1608Metric
R2: 10KΩ; R_0603_1608Metric
R5, R6: 5K1; R_0603_1608Metric
RG1: 56Ω; R_0603_1608Metric
RR1: 68Ω; R_0603_1608Metric
RY1: 62Ω; R_0603_1608Metric
SD1, SD2, SD3: Conn_01x03; PinSocket_1x03_P2.54mm_Vertical
Vin: GCT_USB4125-GF-A-0190_REVA2
X0, X1, X2, X3, X4, X5, X6: Conn_01x03; PinHeader_1x03_P2.54mm_Horizontal
gndpad: SolderWirePad_1x01_SMD_1x2mm

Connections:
unnamed: +.1, C1.1, ESP1.15 (Vin), Vin.A9, Vin.B9
unnamed: -.1, C1.2, ESP2.14 (GND), R5.2, R6.2, Vin.A12, Vin.B12, X0.3, X1.3, X2.3, X3.3, X4.3, X5.3, X6.3
unnamed: C2.1, DH1.1 (GND), ESP1.14 (GND), IC1.6 (INH), IC1.7 (VEE), IC1.8 (VSS), RG1.2, RR1.2, RY1.2, SD1.2, SD2.2, SD3.2
unnamed: DH1.3 (SCL), ESP2.2 (D1)
unnamed: DH1.4 (SDA), ESP2.3 (D2)
unnamed: C2.2, DH1.2 (VCC), DHT11.1 (VCC), ESP1.11 (3V3), ESP2.6 (GND), IC1.16 (VDD), PHR1.1, R2.1, SD1.3, SD2.3, SD3.3, X0.2, X6.2
unnamed: DHT11.4 (GND), ESP2.7 (3V3), R1.1, gndpad.1
unnamed: DHT11.2 (IO), ESP2.4 (D3), R2.2
unnamed: ESP1.1 (A0), IC1.3 (X)
unnamed: ESP1.6 (SD1), SD1.1
unnamed: ESP1.5 (SD2), SD2.1
unnamed: ESP1.4 (SD3), SD3.1
unnamed: ESP2.1 (D0), IC1.9 (C)
unnamed: ESP2.5 (D4), IC1.10 (B)
unnamed: ESP2.8 (D5), LEDG1.2 (A)
unnamed: ESP2.9 (D6), LEDY1.2 (A)
unnamed: ESP2.10 (D7), LEDR1.2 (A)
unnamed: ESP2.11 (D8), IC1.11 (A)
unnamed: IC1.13 (X0), X0.1
unnamed: IC1.14 (X1), X1.1
unnamed: IC1.15 (X2), X2.1
unnamed: IC1.12 (X3), X3.1
unnamed: IC1.1 (X4), X4.1
unnamed: IC1.5 (X5), X5.1
unnamed: IC1.2 (X6), X6.1
unnamed: IC1.4 (X7), PHR1.2, R1.2
unnamed: ESP2.15 (3V3), X1.2, X2.2, X3.2, X4.2, X5.2
unnamed: LEDG1.1 (K), RG1.1
unnamed: LEDR1.1 (K), RR1.1
unnamed: LEDY1.1 (K), RY1.1
unnamed: R5.1, Vin.A5
unnamed: R6.1, Vin.B5

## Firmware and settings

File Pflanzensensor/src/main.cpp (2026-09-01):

/**
 * @file main.cpp
 * @brief Main program for ESP8266 based sensor system
 * @details Modularized initialization with separate files for:
 *          - System initialization (main_init.cpp)
 *          - WiFi/NTP (main_wifi.cpp)
 *          - Sensors (main_sensors.cpp)
 *          - Web server (main_web.cpp)
 *          - LED traffic light (main_led.cpp)
 */

// Arduino & ESP Core
#include <Arduino.h>
#ifdef ESP32
#include <WiFi.h>
#else
#include <ESP8266WiFi.h>
#endif
#include <LittleFS.h>
#include <Wire.h>

// System Components
#include "chronik/chronik_store.h"
#include "configs/config.h"
#include "mail/mail_sender.h"
#include "utils/helper.h"
#include "utils/result_types.h"

// Manager Classes
#include "managers/manager_config.h"
#include "managers/manager_display.h"
#include "managers/manager_led_traffic_light.h"
#include "managers/manager_resource.h"
#include "managers/manager_sensor.h"

// Network & Services
#if USE_WIFI
#include "utils/wifi.h"
#endif

#if USE_WEBSERVER
#include "web/core/web_manager.h"
#endif

// Prometheus Metrics
#if USE_PROMETHEUS_METRICS
#include "metrics/prometheus_metrics.h"
#endif

// Memory Management
#include "utils/memory_manager.h"

// Modular initialization files
#include "main_init.h"
#include "main_led.h"
#include "main_sensors.h"
#include "main_web.h"
#include "main_wifi.h"

// Global objects
extern std::unique_ptr<SensorManager> sensorManager;
extern ResourceManager& ResourceMgr;
extern MemoryManager& MemoryMgr;
#if USE_DISPLAY
extern std::unique_ptr<DisplayManager> displayManager;
#endif
#if USE_LED_TRAFFIC_LIGHT
extern std::unique_ptr<LedTrafficLightManager> ledTrafficLightManager;
#endif

/**
 * @brief System setup - Initialize all components
 */
void setup() {
  // Initialize serial communication first
  Serial.begin(115200);
  Serial.setDebugOutput(true); // Enable debug output to serial
  delay(1000);                 // Give sensors time to power up and stabilize

  // Initialize memory manager FIRST
  MemoryMgr.init();
  MemoryMgr.logState("setup_start");

  // **ULTRA-CRITICAL: Check for flash restore BEFORE ANYTHING ELSE**
  if (!initializeSystem()) {
    return; // Failed or rebooted
  }

  // Filesystem initialized
  LOG_INFO(F("main"), F("Initialisiere Dateisystem"));

  // Initialize display (optional, don't fail on error)
#if USE_DISPLAY
  if (!Helper::initializeComponent(F("display manager"), []() -> ResourceResult {
        displayManager = std::make_unique<DisplayManager>();
        return displayManager->init();
      })) {
    // Note: Don't return here - display is optional
    LOG_WARN(F("main"), F("Display-Manager Initialisierung fehlgeschlagen, fahre fort"));
  } else {
    displayManager->showLogScreen(F("Filesystem..."), true);
  }
#endif

  // Die LED-Ampel wird weiter unten über initializeLedTrafficLight()
  // eingerichtet. Hier stand vorher eine zweite, vollständige Initialisierung -
  // der Manager wurde angelegt und init() gerufen, weiter unten dann erneut.

  // Show boot progress
  showBootProgress(F("Config..."));

  // Initialize configuration
  if (!Helper::initializeComponent(F("configuration"), []() -> ResourceResult {
        auto result = ConfigMgr.loadConfig();
        if (!result.isSuccess()) {
          LOG_ERROR(F("main"),
                    String(F("Konfiguration konnte nicht geladen werden: ")) + result.getMessage());
          return ResourceResult::fail(ResourceError::CONFIG_ERROR, result.getMessage());
        }
        return ResourceResult::success();
      })) {
#if USE_DISPLAY
    if (displayManager)
      displayManager->updateLogStatus(F("Config Fehler"), true);
#endif
    return;
  }

#if USE_DISPLAY
  if (displayManager)
    displayManager->updateLogStatus(F("Config..."), true);
#endif

  // Increase reboot count
  Helper::incrementRebootCount();

  // Handle boot loop recovery: turn off flash file logging if stuck
  if (LittleFS.exists("/.disable_file_log")) {
    LittleFS.remove("/.disable_file_log");
    logger.enableFileLogging(false);
    if (ConfigMgr.isFileLoggingEnabled()) {
      LOG_WARN(F("main"), F("Boot-Schleife erkannt: Datei-Logging wird deaktiviert"));
      ConfigMgr.setFileLoggingEnabled(false);
    }
  }

  // Handle boot loop recovery: clear firmware upgrade flag if stuck
  if (LittleFS.exists("/.clear_upgrade_flag")) {
    LittleFS.remove("/.clear_upgrade_flag");
    if (ConfigMgr.getDoFirmwareUpgrade()) {
      LOG_WARN(F("main"), F("Boot-Schleife erkannt: Firmware-Upgrade-Flag wird gelöscht"));
      ConfigMgr.setDoFirmwareUpgrade(false);
    }
  }

  // **CRITICAL FIX: Check for update mode BEFORE initializing heavy managers**
  if (ConfigMgr.getDoFirmwareUpgrade()) {
    LOG_INFO(F("main"), F("Firmware-Upgrade-Modus erkannt - wechsle in Minimalmodus"));

#if USE_DISPLAY
    // Inform user about update mode on display
    if (displayManager) {
      displayManager->showLogScreen(F("Firmware-Update-Modus"), false);
      displayManager->updateLogStatus(F("Starte Minimal-Setup..."), false);
    }
#endif

    // Setup WiFi for update mode
    auto wifiResult = setupWiFiWithDisplay(displayManager != nullptr);
    if (!wifiResult.isSuccess()) {
      LOG_ERROR(F("main"), F("WiFi-Initialisierung für Update-Modus fehlgeschlagen"));
    }

#if USE_DISPLAY
    // WiFi status display
    if (displayManager) {
      if (WiFi.status() == WL_CONNECTED) {
        displayManager->updateLogStatus(F("WiFi verbunden"), false);
        displayManager->updateLogStatus(String(F("SSID: ")) + WiFi.SSID(), false);
        displayManager->updateLogStatus(String(F("IP: ")) + WiFi.localIP().toString(), false);
      } else {
        displayManager->updateLogStatus(F("WiFi nicht verbunden"), false);
      }
    }
#endif

    // Initialize minimal web server for OTA updates
    if (!Helper::initializeComponent(F("minimal web server"), []() -> ResourceResult {
          if (!WebManager::getInstance().beginUpdateMode()) {
            return ResourceResult::fail(ResourceError::WEBSERVER_ERROR,
                                        F("Initialisierung des minimalen "
                                          "Webservers fehlgeschlagen"));
          }
          return ResourceResult::success();
        })) {
      return;
    }

#if USE_DISPLAY
    // Show successful setup completion
    if (displayManager) {
      displayManager->updateLogStatus(F("Webserver bereit"), false);
      delay(500);
      displayManager->endUpdateMode();
    }
#endif

    LOG_INFO(F("main"), F("Minimal-Update-Modus Setup abgeschlossen"));
    return; // Exit setup() early - don't initialize other managers
  }

#if USE_DISPLAY
  // Inform user about normal mode on display
  if (displayManager) {
    displayManager->updateLogStatus(F("Normalmodus startet..."), true);
  }
#endif

  // Initialize WiFi first (required for web server and NTP)
  showBootProgress(F("WiFi..."));
  auto wifiResult = setupWiFiWithDisplay(displayManager != nullptr);
  if (!wifiResult.isSuccess()) {
    LOG_WARN(F("main"),
             String(F("WiFi-Initialisierung fehlgeschlagen: ")) + wifiResult.getMessage());
    // Continue anyway - AP mode may be active for configuration
  }

  // Zwischendurch schreiben: loop() läuft erst nach setup(), und allein die
  // WiFi-Einrichtung dauert bis zu 15 s. Ohne diese Aufrufe läuft der
  // Logpuffer während des Hochlaufs über und verwirft genau die Zeilen, die
  // man beim Nachvollziehen einer Boot-Schleife braucht.
  logger.flushFileLog();

  // Initialize all major subsystems
  initializeLedTrafficLight();
  logger.flushFileLog();
  initializeSensors();
  logger.flushFileLog();
  initializeWebServer();
  logger.flushFileLog();

#if USE_PROMETHEUS_METRICS
  // Initialize Prometheus metrics system
  PrometheusMetrics::getInstance().begin();
#endif

#if USE_DISPLAY
  if (displayManager) {
    if (isCaptivePortalAPActive()) {
      displayManager->updateLogStatus(F("Setup abgeschlossen"), true);
      displayManager->updateLogStatus(F("WiFi einrichten möglich"), true);
    } else {
      displayManager->updateLogStatus(F("Setup abgeschlossen"), true);
    }
  }
#endif

#if USE_DISPLAY
  if (displayManager) {
    // Add delay before ending boot mode so user can read the information
    delay(1000); // 1 second delay
    displayManager->endBootMode();
  }
#endif

  MailSender::instance().begin();

  logger.endMemoryTracking(F("managers_init"));
  logger.logMemoryStats(F("setup_complete"));
  LOG_INFO(F("main"), F("Setup abgeschlossen"));
  logger.flushFileLog();

  // Sensor settings are now applied directly during JSON parsing
  // DO NOT trigger a synchronous initial measurement here - it may block
  // the webserver while the measurement cycle (and associated LittleFS
  // flushes) complete. Measurements will be handled in loop() periodically
  // and start immediately there, keeping the webserver responsive.
}

/**
 * @brief Main loop - Handle all recurring tasks
 */
void loop() {
  static unsigned long lastMemoryCheck = 0;
  static unsigned long lastWiFiCheck = 0;
  static unsigned long lastMeasurementUpdate = 0;
  static unsigned long lastUpdateModeLog = 0;
  static unsigned long lastMemoryLog = 0;
  static unsigned long lastNtpSync = 0;
  static bool bootLoopCounterCleared = false;
  const unsigned long currentMillis = millis();

  // Clear boot loop counter after 60s of stable uptime
  if (!bootLoopCounterCleared && currentMillis > 60000) {
    LittleFS.remove("/.boot_loop");
    bootLoopCounterCleared = true;
  }

  // Memory monitoring - check every 30 seconds
  if (currentMillis - lastMemoryCheck >= 30000) {
    // Notfall-Bereinigung bei niedrigem Heap
    MemoryMgr.checkAndCleanup(4000);

    // Log detailed memory state every 2 minutes
    if (currentMillis - lastMemoryLog >= 120000) {
      MemoryMgr.logState("loop");
      lastMemoryLog = currentMillis;
    }

    // Check for issues
    if (MemoryMgr.isCritical()) {
      LOG_ERROR(F("main"), F("CRITICAL: Heap below 3KB! "));
      if (sensorManager) {
        sensorManager->cleanup();
      }
    }

    if (MemoryMgr.isHighFragmentation()) {
      LOG_WARN(F("main"), F("High fragmentation: "));
      MemoryMgr.checkMemory();
    }

    lastMemoryCheck = currentMillis;
  }

  // Handle update mode if active
  if (ConfigMgr.getDoFirmwareUpgrade()) {
    auto& web = WebManager::getInstance();
    unsigned long updateStart = web.getUpdateModeStartTime();
    unsigned long timeout = web.getUpdateModeTimeout();

    // Die Frist wird in JEDEM Durchlauf geprüft, nicht mehr nur alle 30 s
    // zusammen mit der Debug-Ausgabe. Vorher konnte eine 60-Sekunden-Frist
    // erst nach bis zu 90 s auffallen. Sie ist außerdem eine Leerlauffrist:
    // noteUpdateModeActivity() schiebt sie bei jedem Upload-Paket weiter, ein
    // laufender Upload wird also nicht mehr mittendrin abgebrochen.
    if (updateStart > 0 && currentMillis - updateStart > timeout) {
      LOG_WARN(F("main"), F("Update-Mode Timeout erreicht. Beende "
                            "Update-Modus automatisch."));
      ConfigMgr.setUpdateFlags(false, false);
      web.resetUpdateModeStartTime();
      LOG_WARN(F("main"), F("ESP startet neu."));
      ESP.restart(); // Force reboot to reload config and exit update mode
      return;
    }

    // Debug: Log update mode recovery state (every 30 seconds)
    if (currentMillis - lastUpdateModeLog >= 30000) {
      LOG_DEBUG(F("main"), F("[UpdateMode] loop: getDoFirmwareUpgrade()=true"));
      LOG_DEBUG(F("main"), String(F("[UpdateMode] loop: currentMillis=")) + String(currentMillis) +
                               String(F(", updateStart=")) + String(updateStart) +
                               String(F(", timeout=")) + String(timeout));
      lastUpdateModeLog = currentMillis;
    }
    WebManager::getInstance().handleClient();
    yield(); // Allow background tasks without blocking upload
    return;
  }

#if USE_WEBSOCKET
  // Handle WebSocket events first to ensure log messages are captured
  auto& ws = WebSocketService::getInstance();
  if (ws.isInitialized()) {
    ws.loop();
  }
#endif

#if USE_WIFI
  // Jeden Durchlauf: der mDNS-Responder muss eingehende Anfragen zeitnah
  // beantworten, ein 30-Sekunden-Takt wäre dafür zu grob.
  aktualisiereMdns();
#endif

  // WiFi connectivity check
  if (currentMillis - lastWiFiCheck >= 30000) { // Every 30 seconds
#if USE_WIFI
    if (!isCaptivePortalAPActive()) {
      LOG_DEBUG(F("main"), F("Prüfe WiFi-Verbindung"));
      checkWiFiConnection();
    } else {
      // Im AP-Modus regelmäßig prüfen, ob das konfigurierte Netz wieder da ist.
      // Der Versuch läuft nicht-blockierend und lässt den AP weiterlaufen, damit
      // die WiFi-Konfiguration über die Admin-Seite erreichbar bleibt.
      // Das gesamte Timing steckt in checkAPModeRecovery().
      checkAPModeRecovery();
    }
#endif
    lastWiFiCheck = currentMillis;
  }

  // NTP nachführen.
  //
  // Ohne das wird die Uhr genau einmal beim Start gestellt und läuft danach auf
  // ESP-Quarzgenauigkeit weiter - über Tage driftet sie merklich, und genau
  // diese Zeitstempel tragen die Chronik. Höchstens stündlich, weil
  // NTPClient::update() bis zu einer Sekunde auf die UDP-Antwort wartet und in
  // dieser Zeit auch der Webserver steht.
  //
  // Ist noch gar keine Uhr da, wird häufiger versucht: das Gerät kann ohne
  // WLAN gestartet sein und es erst später bekommen. Bis dahin zeichnet die
  // Chronik nichts auf, weil Rahmen ohne plausible Zeit verworfen werden.
  {
    static constexpr unsigned long NTP_RESYNC_INTERVAL = 3600000UL; // 1 Stunde
    static constexpr unsigned long NTP_RETRY_INTERVAL = 60000UL;    // 1 Minute
    // Entscheidend ist, ob eine brauchbare Uhrzeit vorliegt - nicht, ob der
    // NTP-Client angelegt wurde. Scheitert die Synchronisation beim Start
    // (Netz noch nicht bereit), ist der Client initialisiert und die Uhr
    // trotzdem leer; mit isNTPInitialized() als Bedingung wartete das Gerät
    // danach eine volle Stunde, statt es gleich noch einmal zu versuchen.
    const bool uhrLaeuft = Helper::getCurrentTime() > 1600000000;
    const unsigned long ntpInterval = uhrLaeuft ? NTP_RESYNC_INTERVAL : NTP_RETRY_INTERVAL;

    if (currentMillis - lastNtpSync >= ntpInterval) {
      lastNtpSync = currentMillis;
#if USE_WIFI
      if (WiFi.status() == WL_CONNECTED && !isCaptivePortalAPActive()) {
        const time_t vorher = Helper::getCurrentTime();

        logger.initNTP(); // fängt sich selbst ab, wenn schon initialisiert
        logger.updateNTP();

        const time_t nachher = Helper::getCurrentTime();

        if (!uhrLaeuft && nachher > 1600000000) {
          LOG_INFO(F("main"), F("NTP-Zeit nachträglich bekommen"));
        } else if (nachher > 0 && vorher > 0) {
          // Die Abweichung ist die eigentlich interessante Zahl: an ihr sieht
          // man, wie weit der Quarz in einer Stunde davonläuft.
          LOG_INFO(F("main"), String(F("NTP nachgeführt, Abweichung: ")) +
                                  String(static_cast<long>(nachher - vorher)) + F(" s"));
        }
      }
#endif
    }
  }

  // Handle web server requests
#if USE_WEBSERVER
  WebManager::getInstance().handleClient();
#endif

  // Update display if enabled
#if USE_DISPLAY
  if (displayManager) {
    displayManager->update();
  }
#endif

  // Handle sensor measurements
  static constexpr unsigned long MEASUREMENT_UPDATE_INTERVAL =
      1000; // 1s between measurement updates
  if (sensorManager && sensorManager->getState() == ManagerState::INITIALIZED) {
    const bool intervalElapsed =
        (currentMillis - lastMeasurementUpdate >= MEASUREMENT_UPDATE_INTERVAL);

    // Eine manuell ausgelöste Messung wird ohne Takt weitergeschaltet.
    // Im 1-Sekunden-Takt kostet jeder Zustandswechsel bis zu einer Sekunde;
    // bis zur ersten Probe sind das fünf Wechsel und damit mehrere Sekunden
    // Wartezeit, obwohl der Nutzer gerade eben auf "Messen" gedrückt hat.
    if (intervalElapsed || sensorManager->hasForcedMeasurement()) {
      sensorManager->updateMeasurements();
    }

    if (intervalElapsed) {
      // Update LED traffic light status for mode 2
#if USE_LED_TRAFFIC_LIGHT
      if (ledTrafficLightManager) {
        ledTrafficLightManager->updateSelectedMeasurementStatus();
      }
#endif
      lastMeasurementUpdate = currentMillis;
    }
  }

  // Gepufferte Logzeilen in den Flash schreiben. Das ist die EINZIGE Stelle,
  // an der das Dateilogging den Flash anfasst - nie aus einem SDK-Callback
  // und nie mit abgeschalteten Interrupts.
  logger.flushFileLog();

  // Chronik direkt nach dem Log-Flush: eine fällige Log-Rotation braucht
  // kurzzeitig die anderthalbfache Dateigröße und soll den Platz zuerst
  // bekommen. Auch das ist die EINZIGE Stelle, an der die Chronik schreibt.
  ChronikStore::instance().flushIfDue();

  // Mailversand. Ebenfalls nur hier und nirgends sonst: ein TLS-Handshake
  // dauert auf diesem Gerät über eine Sekunde und braucht rund 10 KB Heap am
  // Stück - aus einem Webhandler heraus stünde derweil alles still.
  MailSender::instance().loop();

  // Basic system maintenance
  yield();
  delay(1); // Prevent tight loop
}

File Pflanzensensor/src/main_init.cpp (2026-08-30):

/**
 * @file main_init.cpp
 * @brief System initialization and recovery module
 * @details Handles filesystem initialization, flash recovery, and reboot tracking
 */

#include <Arduino.h>
#include <LittleFS.h>

#include "configs/config.h"
#include "utils/config_backup_utils.h"
#include "utils/critical_section.h"
#include "utils/flash_persistence.h"
#include "utils/helper.h"

// Forward declarations
extern Logger logger;
#if USE_DISPLAY
extern std::unique_ptr<DisplayManager> displayManager;
#endif

/**
 * @brief Detect and handle boot loops
 * @details Tracks rapid reboots using a counter file. If the device reboots
 *          3+ times within BOOT_LOOP_WINDOW_MS (30s), it's considered a boot
 *          loop. In that case: clear firmware upgrade flag and reset the counter.
 *          The counter is reset to 0 after BOOT_LOOP_WINDOW_MS of stable uptime.
 */
static void checkBootLoop() {
  constexpr const char* BOOT_LOOP_FILE = "/.boot_loop";
  constexpr int BOOT_LOOP_THRESHOLD = 3;
  constexpr unsigned long BOOT_LOOP_WINDOW_MS = 30000; // 30 seconds

  // Read current count and timestamp
  int count = 0;
  unsigned long lastBootMs = 0;
  if (LittleFS.exists(BOOT_LOOP_FILE)) {
    File f = LittleFS.open(BOOT_LOOP_FILE, "r");
    if (f) {
      count = f.parseInt();
      lastBootMs = f.parseInt();
      f.close();
    }
  }

  unsigned long now = millis();

  // If last boot was recent, increment; otherwise reset
  if (count > 0 && (now - lastBootMs) < BOOT_LOOP_WINDOW_MS) {
    count++;
  } else {
    count = 1;
  }

  // Write updated counter
  File f = LittleFS.open(BOOT_LOOP_FILE, "w");
  if (f) {
    f.print(count);
    f.print(' ');
    f.print(now);
    f.close();
  }

  if (count >= BOOT_LOOP_THRESHOLD) {
    Serial.print(F("BOOT LOOP DETECTED ("));
    Serial.print(count);
    Serial.println(F(" reboots). Clearing firmware upgrade flag and resetting counter."));

    // Clear the boot loop counter
    LittleFS.remove(BOOT_LOOP_FILE);

    // Check if stuck in firmware upgrade mode and clear it
    // (Preferences API not yet initialized here, so we use the config manager later)
    // Write a flag file that main.cpp will pick up after full init
    File flagFile = LittleFS.open("/.clear_upgrade_flag", "w");
    if (flagFile) {
      flagFile.print("1");
      flagFile.close();
    }

    // Das Datei-Logging schreibt in denselben Flash, aus dem das Gerät bootet,
    // und ist damit ein plausibler Auslöser einer Boot-Schleife. Abschalten,
    // damit sich das Gerät von selbst fängt; im Webinterface wieder
    // einschaltbar.
    File logFlag = LittleFS.open("/.disable_file_log", "w");
    if (logFlag) {
      logFlag.print("1");
      logFlag.close();
    }
    LittleFS.remove("/log.txt");
    LittleFS.remove("/log.txt.tmp");

    Serial.println(F("Boot loop recovery flag written. Continuing normal boot."));
  }
}

/**
 * @brief Initialize filesystem and check for recovery needs
 * @return true if initialization successful, false otherwise
 * @details
 * 1. Mount LittleFS
 * 2. Detect boot loops and handle recovery
 * 3. Check for flash restore flag
 * 4. Execute recovery if needed
 * 5. Return success/failure status
 */
bool initializeSystem() {
  // **ULTRA-CRITICAL: Check for flash restore BEFORE ANYTHING ELSE**
  // We need to restore with the absolute cleanest heap possible
  // Don't even initialize logger yet - heap fragmentation is critical
  {
    if (!LittleFS.begin()) {
      Serial.println(F("FATAL: Dateisystem-Mount fehlgeschlagen"));
      return false;
    }
  }

  // Boot loop detection - must run before config is loaded
  checkBootLoop();

  // Check for recovery flag
  if (LittleFS.exists("/.restore_from_flash")) {
    LOG_INFO(F("main_init"),
             F("Wiederherstellungs-Flag gefunden - stelle Konfiguration wieder her"));

    // Remove flag FIRST to prevent infinite loops
    LittleFS.remove("/.restore_from_flash");

    if (FlashPersistence::hasValidConfig()) {
      Serial.print(F("Freier Heap vor Wiederherstellung: "));
      Serial.println(ESP.getFreeHeap());

      // Call restore directly - minimal allocations
      auto result = FlashPersistence::restoreFromFlash();
      if (result.isSuccess()) {
        LOG_INFO(F("main_init"), F("Preferences erfolgreich wiederhergestellt"));

        // Restore JSON config files from /backup/ to /config/
        LOG_INFO(F("main_init"), F("Stelle Config-Dateien wieder her..."));
        if (ConfigBackupUtils::restoreConfigFiles()) {
          LOG_INFO(F("main_init"), F("Config-Dateien erfolgreich wiederhergestellt"));
        } else {
          LOG_WARN(F("main_init"), F("Keine Config-Dateien zum Wiederherstellen gefunden"));
        }

        LOG_INFO(F("main_init"), F("Wiederherstellung abgeschlossen - starte neu..."));
        delay(1000);
        ESP.restart(); // Reboot with restored config
        return false;  // Should never reach here
      } else {
        LOG_ERROR(F("main_init"),
                  String(F("Wiederherstellung fehlgeschlagen: ")) + result.getMessage());
      }
    } else {
      LOG_WARN(F("main_init"), F("Kein gültiges Flash-Backup gefunden"));
    }
  }

  return true;
}

/**
 * @brief Show boot progress on display
 * @param message Message to display
 * @param clearClearPrevious Whether to clear previous message
 */
void showBootProgress(const String& message, bool clearPrevious = false) {
#if USE_DISPLAY
  if (displayManager) {
    displayManager->updateLogStatus(message, clearPrevious);
  }
#endif
}

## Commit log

2023-11-12 some cleanup
    [Configuration.h]
2023-11-13 small fix
    [Configuration.h]
2023-11-14 big update!
    [Configuration.h]
2023-11-14 big update. no dela() in display
    [Configuration.h]
2023-11-15 updates galore
    [Configuration.h]
2023-11-16 big update
    [Configuration.h, Pflanzensensor.fzz]
2023-11-17 doch zwei Eingänge am Multiplexer
    [Pflanzensensor.fzz]
2023-11-17 updates galore!
    [Configuration.h]
2023-11-17 moar updates!
    [Configuration.h]
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2023-11-17 jetzt auch mit Accesspointmodus!
    [Configuration.h]
2023-11-17 small update
    [Configuration.h]
2023-11-18 Routing V1
    [231118_Pflanzensensor_geroutet.fzz]
2023-11-21 Pflanzensensor geroutet V2
    [231120_Pflanzensensor_geroutet_V2.fzz]
2023-11-21 Routing V3
    [231121_Pflanzensensor_geroutet_V3.fzz]
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2023-11-23 other possible nodemcu size
    [Pflanzensensor.fzz]
2023-11-23 small change
    [Pflanzensensor.fzz]
2023-11-23 Routing V4
    [231123_Pflanzensensor_geroutet_V4.fzz]
2023-11-23 small changes
    [Configuration.h]
2023-11-25 D8 statt D0 an Multiplexer wegen interner LED
    [Pflanzensensor.fzz]
2023-11-26 D4 lässt LED blinken
    [Pflanzensensor.fzz]
2023-11-26 LED hassle
    [Pflanzensensor.fzz]
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2023-11-27 kleine Änderungen
    [Configuration.h]
2023-11-27 3-fach Multiplexer, keine interne LED mehr
    [Configuration.h]
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2023-11-27 Viele Kommentare (danke Copilot!)
    [Configuration.h]
2023-11-28 Mehr Analogsensoren!
    [Configuration.h]
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2023-11-29 Umsortieren des Quellcodes
    [Configuration.h]
2023-11-29 Viele Updates
    [Configuration.h]
2023-11-29 Variablen umbenannt
    [Configuration.h]
2023-11-29 Variablen werden jetzt auf Flash gespeichert und nach reboot ausgelesen
2023-12-04 Jetzt mit Debugging
    [Configuration.h]
2023-12-04 großes Update
    [Configuration.h]
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2024-01-23 Wifi Settings geändert
    [Configuration.h]
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2024-01-23 Wifisettings SKD
    [Configuration.h]
2024-05-02 sensible Passwörter in Extradatei
    [Configuration.h]
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2024-05-13 small dirty fix for wifi ap mode
    [Configuration.h]
2024-05-17 mehr Dokumentationsdateien
    [DHT11.stl, Leiterplatte.stl, SSD1306.stl]
2024-05-17 Konfiguration geändert
    [Configuration.h]
2024-05-17 mehr 3D Modelle
    [15-Pin Header - Female - 2.54mm.stl, 3-Pin Header - Female - 2.54mm.stl, 4-Pin Header - Female - 2.54mm.stl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]
2024-05-22 Add files via upload
    1. Prototyp
    [240320_Pflanzensensor_geroutet_V11.fzz]
2024-05-22 Add files via upload
    – INHIBIT auf GND (VEE)
    – Footprint Lichtsensor etwas nach oben verschoben
    – Vorwiderstand Lichtsensor von 10kOhm zu 1kOhm getauscht
    – Beschriftung Analogsensoren verschoben (jetzt darüber)
    [240521_Pflanzensensor_geroutet_V13.fzz]
2024-05-22 Add files via upload
    – 3 M2-Löcher zum Verschrauben im Gehäuse hinzugefügt
    [240521_Pflanzensensor_geroutet_V13.2.fzz]
2024-06-02 STL von Bodenfeuchtesensorgehäuse
    [Bodenfeuchtesensor Gehäuse oben.stl, Bodenfeuchtesensor Gehäuse unten.stl]
2024-08-07 einige webhook updates
    [Configuration.h]
2024-08-07 mehr Updates für den webhook
    [Configuration.h]
2024-08-09 Baudrate gesetzt
    [Configuration.h]
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2024-08-09 mutex wieder an.
    [Configuration.h]
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2024-08-10 webhook überarbeitet
    [Configuration.h]
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2024-08-11 Refactoring webhook: jetzt können alle Sensoren Alarme auslösen
    [Configuration.h]
2024-08-11 Versionsstring 0.5->0.6
    [Configuration.h]
2024-08-11 Revert "Versionsstring 0.5->0.6"
    This reverts commit 63bc1125b0bd40ac31df5f1f074b3726408befec.
    [Configuration.h]
2024-08-11 Display und LED Ampel können ausgschalten werden; Verbesserte Debugausgabe
    [Configuration.h]
2024-08-11 Variablenreset gefixt.
    [Configuration.h]
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2024-08-12 Webhook mit Ping aller X Stunden
    [Configuration.h]
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2024-08-12 Version 0.6
    [Configuration.h]
2024-08-12 Anpassen der default Webhook Frequenzen
    [Configuration.h]
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2024-08-13 Webhook mit allen Sensordaten und neuer Logik
    [Configuration.h]
2024-08-13 Refactoring LEDAmpel Modul
    [Configuration.h]
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2024-08-14 Produktiondaten + Doku Pflanzensensor_V3
    Die Files aus den Ordnern Assembly und Gerber sind die Produktionsdaten inkl. Stückliste, die der Hersteller für die 100 Stück Bestellung bekommen hat. Die Kicad File ist der aktuelle Stand (August 2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
    [20240606_Pflanzensensor-B_Cu.gbr, 20240606_Pflanzensensor-B_Mask.gbr, 20240606_Pflanzensensor-B_Paste.gbr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]
2024-08-19 bugfix WebhookInit und make.com Vorlagen
2024-08-21 Update Webhook Logik
    [Configuration.h]
2024-08-21 Refactoring PCB und Breadboard Dokumentation
    [231118_Pflanzensensor_geroutet.fzz, 231120_Pflanzensensor_geroutet_V2.fzz, 231121_Pflanzensensor_geroutet_V3.fzz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]
2024-08-21 Version bump 0.7
    [Configuration.h]
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2024-09-04 Versionbump auf V1.0
    [Configuration.h]
2024-09-09 Wifi Accesspoint Passwoerter in passwoerter_Beispiel.h statt Configuration.h
    [Configuration.h]
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2024-09-30 bugfix und verschönerung der Warnung bei veränderten WLAN-Daten
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2024-10-21 Bugfix für Anzeige der SSIDs
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2024-10-21 bugfixes beim logger und kleinigkeiten
    [logger.cpp]
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2024-10-24 Neues Bodenfeuchtesensorgehäuse mit Fabmobil Logo
    [Bodenfeuchtesensor Gehäuse oben.stl, Bodenfeuchtesensor Gehäuse unten.stl, Bodenfeuchtesensor_Gehäuse_oben.stl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]
2024-10-24 Bugfix: Timestamp geht jetzt auch ohne Webhook
    [logger.cpp]
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2025-10-17 Version 2.22.1: CSS Anpassungen und kleinere Fixes
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2025-10-19 Version 2.23.1: kleine Bugfixes und Übersetzungen
    [logger.cpp]
2025-10-19 Version 2.23.4: Übersetzungen und Bugfixes
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2025-10-22 Bugfix Display Sensor
2025-10-22 V2.25.0: Autocal Zeit kann jetzt eingestellt werden, Bugfixes hier und da.
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2025-10-23 v2.25.1: kleinere Bug- und UI-fixes
    [main.cpp]
2025-11-03 Add Preferences library and refactor configuration persistence
    - Added Preferences library to platformio.ini
    - Created preferences_manager.h/.cpp with namespace-based configuration storage
    - Implemented helper functions for all configuration namespaces (general, WiFi, display, log, LED traffic light, debug, sensors)
    - Updated manager_config_persistence.cpp to use Preferences as primary storage
    - Added migration logic from JSON to Preferences with backup
    - Updated loadFromFile to check Preferences first, then migrate from JSON if needed
    - Updated saveToFileMinimal to save to Preferences
    - Updated resetToDefaults to clear all Preferences
    - Added comprehensive German logger messages for all ope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
2025-11-03 Add comprehensive sensor persistence to Preferences
    - Extended preferences_manager to include all sensor measurement fields
    - Added functions for saving/loading sensor settings (name, interval, error state)
    - Added functions for saving/loading measurement settings (thresholds, raw values, autocal)
    - Added getInt/putInt helpers for integer values
    - Updated SensorPersistence to load/save from Preferences instead of JSON
    - Updated loadFromFile to read all sensor data from Preferences
    - Updated saveToFileMinimal to write all sensor data to Preferences
    - Includes analog raw values, calibration mode, and autocal settings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
2025-11-04 Fix compilation error: rename DISPLAY to DISP to avoid Arduino.h macro conflict
    - Renamed PreferencesNamespaces::DISPLAY to PreferencesNamespaces::DISP
    - Updated all references in preferences_manager.cpp and manager_display.cpp
    - Resolves conflict with Arduino.h's #define DISPLAY 0x1 macro
    - Namespace string remains "display" (no functional change)
2025-11-04 Remove obsolete JSON file download/upload functionality
    - Removed handleDownloadConfig() - config no longer stored in JSON file (125 lines)
    - Removed handleDownloadSensors() - sensors no longer stored in JSON file (42 lines)
    - Removed handleUploadConfig() - JSON upload no longer needed with Preferences (130 lines)
    - Removed route registrations for /admin/downloadConfig, /admin/downloadSensors, /admin/uploadConfig
    - Removed download/upload UI buttons from admin page (admin_handler_cards.cpp)
    - Removed download buttons from update/OTA page (web_ota_handler.cpp)
    - Removed upload form handling from admin.js
    - Removed ArduinoJson and PersistenceUtils includes from admin_handler_system.cpp
    - Total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
2025-11-05 Refactor to generic setConfig() method for DRY preferences updates
    - Replaced individual atomic update methods with single generic setConfig()
    - Supports String, int, unsigned int, bool, float, and uint8_t types
    - Uses template specialization for type safety
    - Single method handles all namespaces and config keys
    - Example: setConfig(GENERAL, "dev_name", deviceName)
    - Significantly reduces code duplication (~500 lines removed)
    - Updated ConfigManager and DisplayManager to use generic method
    - Maintains same atomic update behavior with cleaner API
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2025-11-05 Fix Arduino.h DISPLAY macro conflict - use DISP namespace
2025-11-05 Kein default JSON generator mehr + Bugfixes
    [main.cpp]
2025-11-05 Fix OTA handler compilation error and add sensor settings backup framework
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2025-11-05 Increase EEPROM namespace size to fix sensor data storage
2025-11-06 Fix incorrect MainFS.h includes - use config_fs.h instead
    [logger.cpp]
2025-11-06 Implement flash-based configuration persistence for OTA filesystem updates
    - Revert dual LittleFS partition approach (not supported on ESP8266)
    - Add FlashPersistence module to store config in firmware flash area
    - Config stored beyond compiled code using ESP.getSketchSize() + safety margin
    - Survives filesystem OTA updates (firmware partition untouched)
    - Integrate with ConfigPersistence save/restore workflow
    - Update OTA handler to restore from flash instead of LittleFS file
    [logger.cpp, main.cpp]
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2026-08-29 - Unterstützung von ESP32 - nur Rot Modus für LED Ampel - experimentelle Unterstützung für folgende Sensoren: - BMP280 Luftdrucksensor - bis zu 8 DS18B20 Temperatursensor - HX711 Gewichtssensor - MH-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
    [led.cpp, logger.cpp, main.cpp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]
2026-08-29 Sicherheit: Admin-Passwort-Leak über /logs geschlossen
    Die Log-Seite hat das Admin-Passwort im Klartext als window.wsAuth in das
    HTML geschrieben, und /logs war ohne Anmeldung erreichbar:
    $ curl -s http://<geraet>/logs | grep -o "wsAuth = '[^']*'"
    wsAuth = 'Fabmobil'
    Zwei Ursachen, beide behoben:
    - log_handler: window.wsAuth und window.wsPort werden nicht mehr ausgegeben.
    Beide wurden vom Frontend nie ausgewertet - logs.js verbindet sich fest
    mit Port 81.
    - web_manager_init: Die Auth-Middleware hat nur /admin* geprüft, alles
    andere fiel durch. Jetzt Whitelist statt Blacklist: öffentlich sind nur
    noch /, /getLatestValues und die statischen Assets (css/js/img/favicon),
    all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
2026-08-29 Stabilität: exitCriticalOperation repariert, doppelten SensorManager entfernt
    Zwei Probleme in ResourceManager::exitCriticalOperation():
    1. Die Nesting-Logik war wirkungslos. m_inCriticalOperation und
    m_currentOperation wurden am Ende der Funktion bedingungslos
    zurückgesetzt - direkt nach dem Block, der sie eigentlich nur auf
    Nesting-Level 0 zurücksetzen sollte:
    if (m_nestingLevel == 0) {
    m_inCriticalOperation = false;
    }
    m_inCriticalOperation = false; // hebt die Bedingung wieder auf
    m_currentOperation = "";
    Schon das Verlassen einer inneren Operation gab damit die äußere frei.
    Jetzt wird der Zustand nur noch auf oberster Ebene zur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
2026-08-29 Bugfix: AnalogConfig und DHTConfig verdeckten Basis-Member
    AnalogConfig deklarierte eigene Member pin und minimumDelay, DHTConfig ein
    eigenes pin - alle drei existieren bereits in SensorConfig. Die abgeleiteten
    Member verdeckten die der Basisklasse:
    struct AnalogConfig : public SensorConfig {
    uint8_t pin; // verdeckt SensorConfig::pin
    unsigned long minimumDelay; // verdeckt SensorConfig::minimumDelay
    AnalogConfig() : pin(ANALOG_PIN), minimumDelay(ANALOG_MINIMUM_DELAY) { ... }
    };
    Der Konstruktor setzte damit die abgeleiteten Member, während
    Sensor::Sensor() den Wert per Slicing kopiert:
    m_tempConfig = config; // kopiert nur die Basis
    In der Basis blie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
2026-08-29 Bugfix + RAM: Zyklus-Manager gehört jetzt dem Sensor, zwei std::map entfallen
    SensorManager::updateMeasurements() läuft im Sekundentakt und griff pro
    Sensor auf zwei std::map<String, ...> zu:
    auto& stateLog = m_sensorStates[sensor->getId()];
    auto cycleManager = m_cycleManagers[sensor->getId()].get();
    Zwei Probleme:
    1. operator[] LEGT einen Eintrag an, wenn der Schlüssel fehlt. Bei
    m_cycleManagers wurde damit ein leerer unique_ptr eingefügt, statt den
    Fehlerfall zu erkennen - der anschließende .get() lieferte nullptr, und
    die Map wuchs still um einen nutzlosen Eintrag.
    2. Jeder Zugriff ist eine Rot-Schwarz-Baum-Suche mit String-Vergleich, also
    zwei Baumsuchen pro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
2026-08-29 Bugfix: doppelte HTTP-Header entfernt
    Jede HTML-Seite lieferte Header doppelt und teils widersprüchlich aus:
    HTTP/1.1 200 OK
    Content-Type: text/html
    Content-Type: text/html
    Connection: close
    Connection: keep-alive
    Ursache: Component::beginResponse() und BaseHandler::beginChunkedResponse()
    setzten Content-Type und Connection per sendHeader() - obwohl send() den
    Content-Type ohnehin selbst setzt und der ESP8266WebServer die
    Connection-Verwaltung selbst übernimmt. Bei widersprüchlichen
    Connection-Angaben ist das Verhalten dann clientabhängig.
    Dasselbe Muster an zwei weiteren Stellen:
    - handleDownloadLog() setzte Content-Length per sendHeader() UND per
    setContentLength()
    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
2026-08-29 Bugfix: LED-Ampel wurde doppelt initialisiert
    setup() legte den LedTrafficLightManager an und rief init() - und rief
    weiter unten initializeLedTrafficLight() auf, das init() erneut ausführt.
    Der zweite Aufruf war zwar funktional harmlos (der Manager prüft
    if (!ledTrafficLightManager) vor dem Anlegen), aber irreführend: es sah aus,
    als bräuchte es beide Pfade.
    Der erste Block ist entfernt, initializeLedTrafficLight() bleibt die einzige
    Stelle. Nebenbei entfernt: ein leeres if am Ende von setup(), das nur noch
    einen erklärenden Kommentar umschloss.
    Getestet am Gerät - die Initialisierung erscheint jetzt genau einmal im
    Bootlog:
    :I: [main_led] LED-Ampel-Manager Initialisierung gestar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
    [main.cpp]
2026-08-29 Bugfix: globale std::vector<String> im OTA-Handler lokalisiert
    web_ota_handler.cpp definierte auf Dateiebene:
    std::vector<String> css = {"admin"};
    std::vector<String> js = {"ota"};
    Ohne static, ohne anonymen Namespace. Zwei Folgen:
    - Zwei dauerhafte Heap-Allokationen, angelegt bei der statischen
    Initialisierung und nie wieder freigegeben, obwohl sie nur in einer
    einzigen Funktion gebraucht werden.
    - Die Symbole "css" und "js" hatten externe Bindung. Jede weitere Definition
    gleichen Namens in einer anderen Übersetzungseinheit wäre ein ODR-Verstoß
    gewesen - bei so generischen Namen eine Falle, die früher oder später
    zuschnappt.
    Beide sind jetzt lokale const-Variablen in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
2026-08-29 Build: -Wall -Wextra -Wshadow aktiviert und alle Projektwarnungen behoben
    platformio.ini aktivierte bisher nur -Wunused-variable und
    -Wunused-function. Mit den Standardwarnungen wären mehrere der in dieser
    Serie behobenen Fehler schon beim Bauen aufgefallen - allen voran das
    Member-Shadowing in AnalogConfig, das den Mindestabstand zwischen
    Einzelmessungen wirkungslos machte.
    Neu: -Wall -Wextra -Wshadow, dazu -Wno-unused-parameter (die
    Handler-Signaturen der Basisklassen haben zwangsläufig ungenutzte
    Parameter).
    Der erste Lauf meldete 13 Warnungen im Projektcode, alle behoben:
    Substantiell:
    - main.cpp: "variable 'metrics' set but not used" - MemoryMgr.getMetrics()
    wurde in loop() alle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
    [main.cpp]
2026-08-29 Wartbarkeit: toten Code entfernt (2108 Zeilen)
    Nichts davon wurde irgendwo im Projekt referenziert. Vor jeder Löschung
    wurde per Grep über den gesamten Baum geprüft, dass es weder Aufrufe noch
    Einbindungen gibt.
    Komplett gelöschte Dateien (12):
    web/core/web_response_buffer.{h,cpp} ResponseBuffer - eine Pufferklasse
    für genau das Problem, das
    sendChunk() hatte, nur nie benutzt
    web/core/web_helper_params.h ParamParser
    web/core/web_helper_response.{h,cpp} ResponseBuilder
    web/core/web_helper_sensors.{h,cpp} SensorHelper
    web/core/web_helper_ui.{h,cpp} UI-Namespace
    sensors/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
    [logger.cpp]
2026-08-29 Prüfsummen: Verifikation abschaltbar gemacht - und wenn an, dann auch wirklich
    Die CRC32 der Flash-Sicherung wurde beim Speichern berechnet und im Header
    abgelegt, beim Wiederherstellen aber ausdrücklich übersprungen:
    // CRC check skipped - we rely on magic number + version for validation
    Die 1-KB-Tabelle im Flash diente damit einem Wert, den nie jemand geprüft
    hat - beschädigte Konfigurationsdaten wären ungefiltert in die Preferences
    gewandert. Für den JSON-Bereich stand im Header sogar eine feste 0 als
    Platzhalter.
    Umgesetzt:
    1. Eine Einstellung schaltet die Prüfsummen-Verifikation an und aus. Es ist
    das vorhandene general/md5_verify, das schon die MD5-Prüfung beim
    Fir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
2026-08-29 Doku: EEPROM-Angaben korrigiert - Preferences liegen in LittleFS, nicht im EEPROM
    Die Entwicklerdokumentation beschrieb die Persistenz in mehreren Punkten
    falsch, und zwar so, dass es zu Fehlannahmen einlädt:
    "Custom EEPROM partition (16KB) for configuration persistence"
    "Preferences (EEPROM) - Survives filesystem flashes, 16KB"
    "Recent change: EEPROM expanded from 4KB to 16KB"
    "Configuration survives filesystem reflash"
    Nachgeprüft, alle drei Behauptungen stimmen nicht:
    1. Größe: eagle.flash.4mmore.ld definiert _EEPROM_start = 0x405FB000, der
    rfcal-Bereich beginnt bei 0x405FC000. Das sind 4 KB, nicht 16 KB.
    2. Ablageort: Die Preferences-Bibliothek wählt in Preferences_se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
2026-08-29 Bugfix: 9 Sensor-Endpunkte waren nach frischem Boot nicht erreichbar
    Die Lazy-Loading-Middleware im WebManager führte eine zweite, handgepflegte
    Liste, welche URLs zu welchem Handler gehören. Diese Liste war gegenüber den
    tatsächlich registrierten Routen auseinandergelaufen:
    AdminSensorHandler::onRegisterRoutes() registriert 13 Routen
    Middleware lud ihn für 3 davon
    "/admin/sensors", "/trigger_measurement", "/admin/getSensorConfig"
    Die übrigen 9 fielen stattdessen in den allgemeinen "/admin"-Zweig, luden
    also den falschen Handler (AdminHandler) und liefen anschließend ins 404.
    Am Gerät nach einem frischen Boot reproduziert - alle neun:
    /admin/analog_mi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
2026-08-29 Notfallpasswort für den Fall eines vergessenen Adminpassworts
    Neben dem eingestellten Adminpasswort gilt jetzt ein zweites, fest
    eincompiliertes. Zweck: Zugang zum Gerät, wenn das gesetzte Passwort
    vergessen wurde - vorher blieb nur ein Factory-Reset über die serielle
    Schnittstelle oder erneutes Flashen.
    WICHTIG - Tragweite dieser Entscheidung:
    Das Repository und die Firmware-Releases sind öffentlich. Der Wert steht im
    Klartext im Quelltext und lässt sich aus jeder veröffentlichten firmware.bin
    per "strings" auslesen; er ist also kein Geheimnis. In der Konsequenz ist
    jedes Gerät mit dieser Firmware für jeden im selben Netz administrierbar,
    unabhängig davon, welches Adminpasswort ei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
2026-08-29 Compilerwarnungen im eigenen Code auf null, Prüfskript ergänzt
    -Wall/-Wextra/-Wshadow standen in build_flags und galten damit auch für
    Framework und Bibliotheken. Ein sauberer Neubau erzeugte 1383
    -Wshadow-Warnungen, davon nur 3 aus eigenem Code - allein StreamString.h
    des Frameworks steuerte 1170 bei. -Wshadow war so als Signal wertlos,
    obwohl es letzte Runde genau dafür eingeschaltet wurde (verdecktes
    minimumDelay, P3.1).
    Zwei Änderungen:
    1. Die Warnungsflags stehen jetzt in build_src_flags und gelten damit nur
    für Pflanzensensor/src/. Framework- und Bibliotheksquellen werden ohne
    sie übersetzt.
    2. Die drei echten Warnungen in display/display_qrcode.cpp behoben:
    - innere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
2026-08-29 Fehlerzähler zählt wieder aufeinanderfolgende Fehler, keine Abschaltung mehr
    Zwei Fehler in der Fehlerbehandlung, die sich gegenseitig verstärkten.
    1. errorCount zählte nicht das, was dokumentiert ist
    MEASUREMENT_ERROR_COUNT heißt "Anzahl aufeinanderfolgender Fehlmessungen",
    aber m_state.errorCount wurde bei einer erfolgreichen Messung nirgends
    zurückgesetzt - nur nach geglückter Reinitialisierung, in reset() und in
    abortCycle(). Ein Sensor, der gelegentlich eine Messung verpatzt (beim DHT
    völlig normal), summierte die Fehler über Stunden auf und lief in die
    Fehlerbehandlung, obwohl er funktionierte.
    Der Erfolgspfad von handleMeasuring() setzt jetzt errorCount, fatalError,
    die ne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
2026-08-30 Datei-Logging puffert im RAM und schreibt nur noch aus loop()
    Bisher schrieb jede Logzeile sofort in den Flash - aus writeToFile(), das
    direkt an log() hing. log() ist aber aus beliebigem Kontext erreichbar, auch
    aus einem SDK-Callback. Ein Flash-Schreibvorgang von dort legt den WiFi-Stack
    lahm (Exception 2 im sys-Kontext, danach WDT-Reset). Dazu kam ein
    Flash-Schreibzugriff pro Logzeile, was den Flash unnoetig verschleisst.
    Logzeilen sammeln sich jetzt in einem RAM-Puffer (bufferForFile(), 1 KB
    Obergrenze) und landen ausschliesslich in flushFileLog() im Flash - gerufen
    aus loop() und an den Phasengrenzen von setup(). Geschrieben wird, sobald
    512 Bytes aufgelaufen sind oder 5 s vergangen si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
    [logger.cpp, main.cpp, main_init.cpp]
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2026-08-31 Uhrzeit stündlich per NTP nachführen
    Die Uhr wurde genau einmal beim Start gestellt: logger.updateNTP() stand nur in
    der Warteschleife von main_wifi.cpp. Danach rechnete NTPClient::getEpochTime()
    die Zeit aus dem letzten Abgleich plus millis() hoch - also auf
    ESP-Quarzgenauigkeit. Über Tage driftet das merklich, und genau diese
    Zeitstempel tragen jetzt die Zeitachse der Chronik.
    loop() führt die Zeit deshalb höchstens stündlich nach. Nicht öfter, weil
    NTPClient::update() über forceUpdate() bis zu einer Sekunde auf die
    UDP-Antwort wartet und in dieser Zeit auch der Webserver steht.
    Zweiter Fall, der dabei mit abfällt: war beim Start kein WLAN da, wurde NTP nie
    initialisiert und bli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
    [logger.cpp, main.cpp]
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2026-08-31 Neustart nach Testmail behoben, Startmeldung wartet auf die Sensoren
    Drei Befunde aus dem Betrieb, zwei davon mit derselben Ursache.
    1. Der Neustart nach dem Versand kam aus cleanupNonEssentialHandlers().
    Die Funktion zerstört die Handler des Webservers, entfernte deren Routen
    aber nicht aus dem Router - anders als die LRU-Verdrängung zwei Funktionen
    weiter, die genau das tut. Die Lambdas der Routen fangen den Handler per
    Zeiger; nach dem Aufräumen zeigten sie ins Leere. Der MailSender ruft die
    Funktion vor jedem Versand auf (mail_sender.cpp:370), also stürzte das
    Gerät beim nächsten Aufruf einer vorher besuchten Seite ab.
    Eine erneute Registrierung reparierte da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
2026-09-01 Absturz beim Mailversand behoben, Datei-Log verkleinert, tote Route entfernt
    Drei Sachen aus dem Betrieb.
    1. Beim Versenden stürzte das Gerät ab: Exception 29, Schreibzugriff auf
    0x00000000 - eine Allokation lieferte nullptr, und niemand prüft das.
    Der Handshake verbraucht gemessen 11,7 KB; die Schwelle von 14000 ließ
    damit einen Rest von 2,3 KB zu, und den überlebt der Versand nicht.
    Entscheidend war aber nicht die Zahl allein. Zwei Versuche mit praktisch
    gleichem freien Heap gingen unterschiedlich aus - bei einem lief eine
    Browseranfrage mit. Deshalb hält der Webserver jetzt für die Dauer des
    Verbindungsaufbaus an (RAII-Wächter, damit auch jeder Fehlerausgang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
